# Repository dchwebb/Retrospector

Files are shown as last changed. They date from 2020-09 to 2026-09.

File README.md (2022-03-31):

# Retrospector
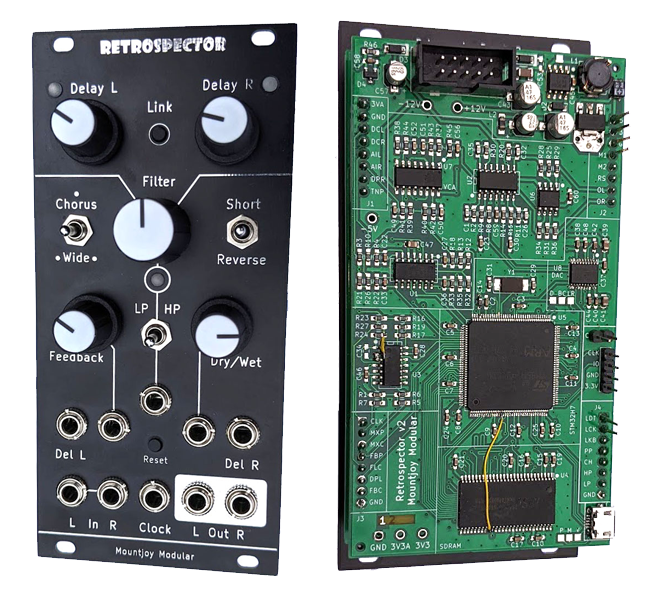
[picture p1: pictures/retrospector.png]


Retrospector is a Eurorack format stereo digital delay. 

Delay times can be set clocked or free-running and left and right channels can be independent or the right channel set as a multiple of the left channel. The delay times are switchable between short, long and reversed with maximum delay times over 5 minutes.

The feedback path can be filtered with settings allowing a sweep from low pass to high pass, or either separately. The delayed signal can be modulated for subtle chorussing effects or left and right channels fed back into each other to widen dual mono sources.

The feedback control allows greater than 100% regeneration allowing the delay to increase the volume of the delayed signal.

Three RGB LEDs display the delay times (using different colours to indicate clocking and channel linking) and the filter status (white to red with increasing low pass filtering and white to blue for high pass).

A USB port is available on the rear of the module providing configuration, debug and upgrade options via a serial interface.

# Technical
The module is constructed from a sandwich of three PCBs. The front panel is held to the control PCB using the potentiometers and jack sockets with light guides directing the RGB LEDs from the control PCB. The control PCB also houses the LED driver. All other components are on the component PCB and this is attached to the control PCB with standard 2.54mm headers. The component board is a 4 layer PCB; the others have 2 layers.

Retrospector is built around an STM32H743 microcontroller clocked at 400MHz. The MCU uses a pair of multi-channel 16-bit ADCs to digitise the stereo audio input signal and the various potentiometer and control voltage inputs.

The MCU controls the external DAC with I2S at 16 bits. The MCU's internal 12-bit DACs are used to control the linear VCA that carries out stereo mixing of the digital wet signal and analog dry signal.

Delay samples are held in external 32MB SDRAM controlled by the MCU's FMC peripheral. The MCU's internal memory is mainly used for DMA buffers and FIR filter buffers (better performance than the slower external RAM). The MCU also has both data and instruction caches which are used to greatly improve performance.

The three RGB LEDs are controlled by a Toshiba 9 channel LED driver (TB62781FNG) with the MCU setting colour and brightness over SPI and DMA.

The MCU also supports a USB micro-B port to allow upgrades, configuration and debugging via a serial console:

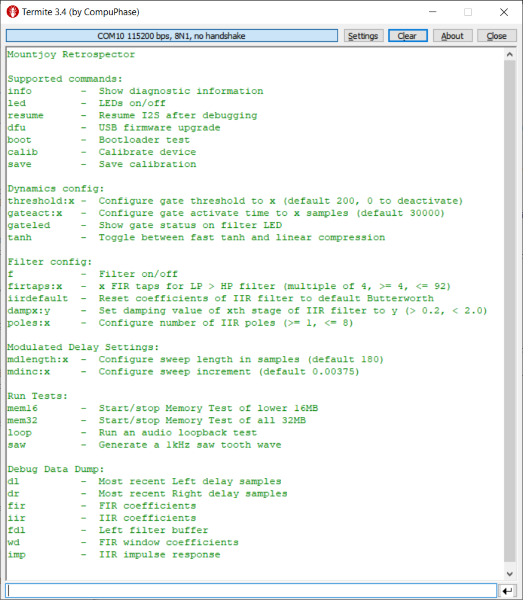
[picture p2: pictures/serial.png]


Annotated component PCB
-----------------------
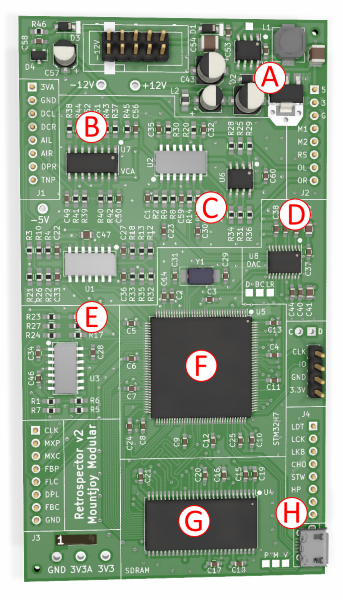
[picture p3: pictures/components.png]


A) A switched-mode power supply (Texas Instruments LM2675) converts the 12V rail to 5V which is then converted to 3.3V using an LDO. THe 5V rail also powers the RGB LEDs.

B) The mix control uses a 4 channel linear VCA (Alfa AS3364D) to control the Wet/Dry mix. This keeps the dry signal analog throughout.

C) The Output signals are mixed and inverted (to preserve signal polarity) with a TL074 and a TL072 op-amp.

D) The digital Wet signal is converted to analog using a Texas Instruments PCM5100 DAC.

E) The analog input signals (audio and control voltage) are scaled and mixed using a pair of MCP6004 op-amps.

F) The microcontroller is an STM32H743 running at 400MHz.

G) The delay beffers are stored in an external 32MB RAM module (ISSI IS42S16160J) allowing for over 5 minutes of stereo delay.

Errata
------
There were two errors on v2 hardware:

1. OpAmp U3 pin 2 and 3 incorrectly swapped. Bodge is to ground pin 3 of U3, remove capacitor C34, lift U3 pin 2 and connect it with a bodge wire to pad 2 of R24.
2. DRAM address line 12 was not connected. Bodge is to connect DRAM Pin 36 to MCU Pin 87.
3. Swapped C54 (tantalum 22uF) for ceramic 47uF (1206 25V X5R).

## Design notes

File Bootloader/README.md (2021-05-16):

# Boottest_H743
Test running bootloader from different Flash address. Project tests basic blinky functionality in a loop and from a timer interrupt to establish that running from different flash region works.

Flash start location is set in linker script to Bank 2 sector 1:

```
FLASH (rx)     : ORIGIN = 0x08100000, LENGTH = 1024K
```

assembly startup script then takes origin of vector table and updates SCB->VTOR register:

```
  ldr r3, =0xe000ed00    // SCB location
  ldr r2, =g_pfnVectors  // Location of vector table in Flash (set by linker)
  str r2, [r3, #8]       // store vector table location to offset 8 of SCB which is VTOR
```

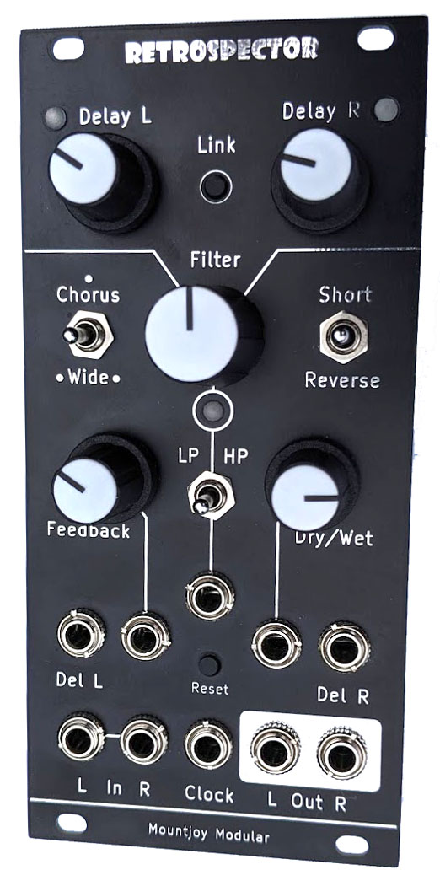
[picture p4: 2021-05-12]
pictures/front.jpg

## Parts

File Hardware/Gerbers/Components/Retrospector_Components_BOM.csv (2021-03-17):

Comment | Designator | Footprint | LCSC Part #
100pF | C1, C26, C32, C35, | C_0603_HandSoldering | C14858
100nF | C2, C3, C4, C5, C6, C7, C8, C9, C10, C11, C12, C13, C14, C15, C16, C17, C18, C19, C20, C21, C37, C38, C40, C44, C53, C58, | C_0603_HandSoldering | C14663
1.5nF | C22, C27, C28, C33, C34, C36, | C_0603_HandSoldering | C1595
1nF | C23, C30, | C_0603_HandSoldering | C1588
2.2uF | C24, C25, C42, C46, C48, C59, C60, | C_0603_HandSoldering | C23630
30pF | C29, C31, | C_0603_HandSoldering | C22397
10uF | C39, C41, C47, | C_0805 | C15850
47uF | C43, C61, | CP_Elec_5x5.8 | C134798
10nF | C45, C56, | C_0603_HandSoldering | C57112
560pF | C49, C50, C51, C52, | C_0603_HandSoldering | C84721
22uF | C57, C62, | CP_Elec_4x5.8 | C134793
1N5819 | D1, D2, D3, | D_SOD-123 | C8598
LM4040DBZ-5 | D4, | SOT-23 | C156291
L | L2, | L_0805_HandSoldering | C1046
75k | R1, | R_0603_HandSoldering | C23242
47k | R2, R6, R7, R10, R11, R18, R22, R24, R33, | R_0603_HandSoldering | C25819
20k | R3, R12, | R_0603_HandSoldering | C4184
6k8 | R4, R13, | R_0603_HandSoldering | C23212
91k | R5, R16, | R_0603_HandSoldering | C23265
2k2 | R8, R14, R46, | R_0603_HandSoldering | C4190
10k | R9, R15, R25, R28, R31, R34, | R_0603_HandSoldering | C25804
56k | R17, | R_0603_HandSoldering | C23206
100k | R19, R26, R27, R35, | R_0603_HandSoldering | C25803
30k | R20, R30, R37, R38, R39, R40, | R_0603_HandSoldering | C22984
68k | R21, R23, R32, | R_0603_HandSoldering | C23231
1k | R29, R36, | R_0603_HandSoldering | C21190
510R | R41, R42, R43, R44, | R_0603_HandSoldering | C23193
100R | R45, | R_0603_HandSoldering | C22775
MCP6004 | U1, U3, | SOIC-14_N | C116668
TL074 | U2, | SOIC-14_N | C6964
IS42S16800F-7TLI | U4, | TSOP-II-54_22.2x10.16mm_P0.8mm | C91278
STM32H743ZITx | U5, | LQFP-144_20x20mm_P0.5mm | C114408
TL072 | U6, | SOIC-8_3.9x4.9mm_Pitch1.27mm | C6961
PCM5100APW | U8, | SSOP-20_4.4x6.5mm_Pitch0.65mm_Round_Pads | C131154
LM2675M-5 | U9, | SOIC-8_3.9x4.9mm_Pitch1.27mm | C180371
8MHz 20pF | Y1, | Crystal_SMD_5032-2pin_5.0x3.2mm_HandSoldering | C115962

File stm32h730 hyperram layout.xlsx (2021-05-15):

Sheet: ProductsList
Part Number | General Description | Marketing Status | Core | Operating Frequency (MHz) | Co-Processor type | Co-Processor frequency (MHz) max | Flash Size (kB) (Prog) | Dual-bank Flash | RAM Size (kB) | ITCM/DTCM RAM (kB) | Timers (16-bit) typ | Timers (32-bit) typ | Other timer functions | A/D Converters 12-bit |  | A/D Converters 16-bit |  | D/A Converters (12-bit) typ | Comparator | I/Os (High Current) | Display controller | CAN FD typ | I2C typ | SPI typ | I2S typ | USART typ | UART typ | External Memory Interfaces | USB Type | Crypto-HASH | TRNG typ | SMPS | Supply Voltage (V) min | Supply Voltage (V) max | Supply Current (µA) (@ Lowest Power) typ | Supply Current (µA) (Run Mode (per MHz)) typ | Operating Temperature (°C) min | Operating Temperature (°C) max | Buy On Line
 |  |  |  |  |  |  |  |  |  |  |  |  |  | Number of A/D Converters typ | Number of Channels typ | Number of A/D Converters typ | Number of Channels typ
STM32H735IG (https://www.st.com/en/product/stm32h735ig.html) | High-performance and DSP with DP-FPU, Arm Cortex-M7 MCU with 1 MByte Flash, 564 KBytes RAM, 550 MHz CPU, L1 cache, external memory interface, SMPS, subset of peripherals including a Crypto accelerator | Active | Arm Cortex-M7 | 550 | Cordic,FMAC | 275 | 1024 | false | 564 | 64/128 | 17 | 4 | Dual Watchdog,LP timer,RTC,SysTick | 1 | 12,17 | 2 | 18,22 | 2 | 2 | 119,128 | Segment LCD | 3 | 5 | 6 | 4 | 5 | 6 | Dual Quad SPI,FMC | USB OTG HS | AES,DES/TDES,HMAC,MD5,SHA | true | Internal | 1.62 | 3.6 | 4 | 150 | -40 | 125,85 | true
STM32H723VE (https://www.st.com/en/product/stm32h723ve.html) | High-performance and DSP with DP-FPU, Arm Cortex-M7 MCU with 512 Kbytes Flash, 564 Kbytes RAM, 550 MHz CPU, L1 cache, external memory interface, subset of peripherals | Active | Arm Cortex-M7 | 550 | Cordic,FMAC | 275 | 512 | false | 564 | 64/128 | 17 | 4 | Dual Watchdog,HR timer,LP timer,RTC,SysTick | 1 | 17,4 | 2 | 14 | - | 2 | 80 | Segment LCD | 3 | 5 | 5 | 4 | 5 | 6 | Dual Quad SPI,FMC | USB OTG HS | - | true | - | 1.62,1.71 | 3.6 | 4 | 270 | -40 | 85 | false
STM32H723VG (https://www.st.com/en/product/stm32h723vg.html) | High-performance and DSP with DP-FPU, Arm Cortex-M7 MCU with 1 MByte Flash, 564 Kbytes RAM, 550 MHz CPU, L1 cache, external memory interface, subset of peripherals | Active | Arm Cortex-M7 | 550 | Cordic,FMAC | 275 | 1024 | false | 564 | 64/128 | 17 | 4 | Dual Watchdog,HR timer,LP timer,RTC,SysTick | 1 | 17,4 | 2 | 14 | - | 2 | 80 | Segment LCD | 3 | 5 | 5 | 4 | 5 | 6 | Dual Quad SPI,FMC | USB OTG HS | - | true | - | 1.62,1.71 | 3.6 | 4 | 270 | -40 | 85 | false,true
STM32H723ZE (https://www.st.com/en/product/stm32h723ze.html) | High-performance and DSP with DP-FPU, Arm Cortex-M7 MCU with 512 Kbytes Flash, 564 Kbytes RAM, 550 MHz CPU, L1 cache, external memory interface, subset of peripherals | Active | Arm Cortex-M7 | 550 | Cordic,FMAC | 275 | 512 | false | 564 | 64/128 | 17 | 4 | Dual Watchdog,HR timer,LP timer,RTC,SysTick | 1 | 12,17 | 2 | 16,18 | - | 2 | 112,114 | Segment LCD | 3 | 5 | 6 | 4 | 5 | 6 | Dual Quad SPI,FMC | USB OTG HS | - | true | - | 1.62 | 3.6 | 4 | 270 | -40 | 85 | false
STM32H723ZG (https://www.st.com/en/product/stm32h723zg.html) | High-performance and DSP with DP-FPU, Arm Cortex-M7 MCU with 1 MByte Flash, 564 KB RAM, 550 MHz CPU, L1 cache, external memory interface, subset of peripherals | Active | Arm Cortex-M7 | 550 | Cordic,FMAC | 275 | 1024 | false | 564 | 64/128 | 17 | 4 | Dual Watchdog,HR timer,LP timer,RTC,SysTick | 1 | 12,17 | 2 | 16,18 | - | 2 | 112,114 | Segment LCD | 3 | 5 | 6 | 4 | 5 | 6 | Dual Quad SPI,FMC | USB OTG HS | - | true | - | 1.62 | 3.6 | 4 | 270 | -40 | 85 | false,true
STM32H725AE (https://www.st.com/en/product/stm32h725ae.html) | High-performance and DSP with DP-FPU, Arm Cortex-M7 MCU with 512 KBytes Flash, 564 KBytes RAM, 550 MHz CPU, L1 cache, external memory interface, SMPS, subset of peripherals | Active | Arm Cortex-M7 | 550 | Cordic,FMAC | 275 | 512 | - | 564 | 64/128 | 17 | 4 | Dual Watchdog,HR timer,LP timer,RTC,SysTick | 1 | 15 | 2 | 22 | 2 | 2 | 121 | Segment LCD | 3 | 5 | 4 | 4 | 5 | 6 | Dual Quad SPI,FMC | USB OTG HS | - | true | Internal | 1.62 | 3.6 | 4 | 150 | -40 | 85 | true
STM32H725AG (https://www.st.com/en/product/stm32h725ag.html) | High-performance and DSP with DP-FPU, Arm Cortex-M7 MCU with 1 MByte Flash, 564 KBytes RAM, 550 MHz CPU, L1 cache, external memory interface, SMPS, subset of peripherals | Active | Arm Cortex-M7 | 550 | Cordic,FMAC | 275 | 1024 | - | 564 | 64/128 | 17 | 4 | Dual Watchdog,HR timer,LP timer,RTC,SysTick | 1 | 15 | 2 | 22 | 2 | 2 | 121 | Segment LCD | 3 | 5 | 4 | 4 | 5 | 6 | Dual Quad SPI,FMC | USB OTG HS | - | true | Internal | 1.62 | 3.6 | 4 | 150 | -40 | 125,85 | true
STM32H725IE (https://www.st.com/en/product/stm32h725ie.html) | High-performance and DSP with DP-FPU, Arm Cortex-M7 MCU with 512 KBytes Flash, 564 KBytes RAM, 550 MHz CPU, L1 cache, external memory interface, SMPS, subset of peripherals | Active | Arm Cortex-M7 | 550 | FMAC, Cordic | 275 | 512 | - | 564 | 64/128 | 17 | 4 | Dual Watchdog,HR timer,LP timer,RTC,SysTick | 1 | 12,17 | 2 | 18,22 | 2 | 2 | 119,128 | Segment LCD | 3 | 5 | 6 | 4 | 5 | 6 | Dual Quad SPI,FMC | USB OTG HS | - | true | Internal | 1.62 | 3.6 | 4 | 150 | -40 | 85 | -
STM32H725IG (https://www.st.com/en/product/stm32h725ig.html) | High-performance and DSP with DP-FPU, Arm Cortex-M7 MCU with 1 MByte Flash, 564 KBytes RAM, 550 MHz CPU, L1 cache, external memory interface, SMPS, subset of peripherals | Active | Arm Cortex-M7 | 550 | Cordic,FMAC | 275 | 1024 | - | 564 | 64/128 | 17 | 4 | Dual Watchdog,HR timer,LP timer,RTC,SysTick | 1 | 17,18 | 2 | 18,22 | 2 | 2 | 119,128 | Segment LCD | 3 | 5 | 6 | 4 | 5 | 6 | Dual Quad SPI,FMC | USB OTG HS | - | true | Internal | 1.62 | 3.6 | 4 | 150 | -40 | 125,85 | false
STM32H725RE (https://www.st.com/en/product/stm32h725re.html) | High-performance and DSP with DP-FPU, Arm Cortex-M7 MCU with 512 KBytes Flash, 564 KBytes RAM, 550 MHz CPU, L1 cache, external memory interface, SMPS, subset of peripherals | Active | Arm Cortex-M7 | 550 | FMAC, Cordic | 275 | 512 | - | 564 | 64/128 | 17 | 4 | Dual Watchdog,HR timer,LP timer,RTC,SysTick | 1 | 2 | 2 | 14 | 2 | 2 | 46 | Segment LCD | 2 | 4 | 4 | 4 | 4 | 4 | Dual Quad SPI,FMC | USB OTG HS | - | true | Internal | 1.71 | 3.6 | 4 | 150 | -40 | 85 | false
STM32H725RG (https://www.st.com/en/product/stm32h725rg.html) | High-performance and DSP with DP-FPU, Arm Cortex-M7 MCU with 1 MByte Flash, 564 KBytes RAM, 550 MHz CPU, L1 cache, external memory interface, SMPS, subset of peripherals | Active | Arm Cortex-M7 | 550 | Cordic,FMAC | 275 | 1024 | - | 564 | 64/128 | 17 | 4 | Dual Watchdog,HR timer,LP timer,RTC,SysTick | 1 | 2 | 2 | 14 | 2 | 2 | 46 | Segment LCD | 2 | 4 | 4 | 4 | 4 | 4 | Dual Quad SPI,FMC | USB OTG HS | - | true | Internal | 1.71 | 3.6 | 4 | 150 | -40 | 125,85 | false
STM32H725VE (https://www.st.com/en/product/stm32h725ve.html) | High-performance and DSP with DP-FPU, Arm Cortex-M7 MCU with 512 KBytes Flash, 564 KBytes RAM, 550 MHz CPU, L1 cache, external memory interface, SMPS, subset of peripherals | Active | Arm Cortex-M7 | 550 | FMAC, Cordic | 275 | 512 | - | 564 | 64/128 | 17 | 4 | Dual Watchdog,HR timer,LP timer,RTC,SysTick | 1 | 4 | 2 | 14 | 2 | 2 | 67 | Segment LCD | 3 | 5 | 5 | 4 | 4 | 4,5 | Dual Quad SPI,FMC | USB OTG HS | - | true | Internal | 1.62,1.71 | 3.6 | 4 | 150 | -40 | 85 | false
STM32H725VG (https://www.st.com/en/product/stm32h725vg.html) | High-performance and DSP with DP-FPU, Arm Cortex-M7 MCU with 1 MByte Flash, 564 KBytes RAM, 550 MHz CPU, L1 cache, external memory interface, SMPS, subset of peripherals | Active | Arm Cortex-M7 | 550 | Cordic,FMAC | 275 | 1024 | - | 564 | 64/128 | 17 | 4 | Dual Watchdog,HR timer,LP timer,RTC,SysTick | 1 | 2,4 | 2 | 14 | 2 | 2 | 67 | Segment LCD | 3 | 5 | 5,6 | 4 | 4 | 5 | Dual Quad SPI,FMC | USB OTG HS | - | true | Internal | 1.62,1.71 | 3.6 | 4 | 150 | -40 | 125,85 | true
STM32H725ZE (https://www.st.com/en/product/stm32h725ze.html) | High-performance and DSP with DP-FPU, Arm Cortex-M7 MCU with 512 KBytes Flash, 564 KBytes RAM, 550 MHz CPU, L1 cache, external memory interface, SMPS, subset of peripherals | Active | Arm Cortex-M7 | 550 | FMAC, Cordic | 275 | 512 | - | 564 | 64/128 | 17 | 4 | Dual Watchdog,HR timer,LP timer,RTC,SysTick | 1 | 12 | 2 | 18 | 2 | 2 | 97 | Segment LCD | 3 | 5 | 6 | 4 | 5 | 6 | Dual Quad SPI,FMC | USB OTG HS | - | true | Internal | 1.62 | 3.6 | 4 | 150 | -40 | 85 | -
STM32H725ZG (https://www.st.com/en/product/stm32h725zg.html) | High-performance and DSP with DP-FPU, Arm Cortex-M7 MCU with 1 MByte Flash, 564 KBytes RAM, 550 MHz CPU, L1 cache, external memory interface, SMPS, subset of peripherals | Active | Arm Cortex-M7 | 550 | Cordic,FMAC | 275 | 1024 | - | 564 | 64/128 | 17 | 4 | Dual Watchdog,HR timer,LP timer,RTC,SysTick | 1 | 12 | 2 | 18 | 2 | 2 | 97 | LCD TFT Controller | 3 | 5 | 6 | 4 | 5 | 6 | Dual Quad SPI,FMC | USB OTG FS + USB OTG FS/HS | - | true | Internal | 1.62 | 3.6 | 4 | 150 | -40 | 125,85 | false,true
STM32H730AB (https://www.st.com/en/product/stm32h730ab.html) | High-performance and DSP with DP-FPU, Arm Cortex-M7 MCU with 128 Kbytes Flash, 564 Kbytes RAM, 550 MHz CPU, L1 cache, external memory interface, SMPS, subset of peripherals including a Crypto accelerator | Active | Arm Cortex-M7 | 550 | Cordic,FMAC | 275 | 128 | false | 564 | 64/128 | 17 | 4 | Dual Watchdog,LP timer,RTC,SysTick | 1 | 15 | 2 | 22 | 2 | 2 | - | Segment LCD | 3 | 5 | 6 | 4 | 5 | 6 | Dual Octo SPI,FMC | USB OTG HS | AES,DES/TDES,HMAC,MD5,SHA | true | Internal | 1.62 | 3.6 | 4 | 150 | -40 | 85 | true
STM32H730IB (https://www.st.com/en/product/stm32h730ib.html) | High-performance and DSP with DP-FPU, Arm Cortex-M7 MCU with 128 Kbytes Flash, 564 Kbytes RAM, 550 MHz CPU, L1 cache, external memory interface, SMPS, subset of peripherals including a Crypto accelerator | Active | Arm Cortex-M7 | 550 | Cordic,FMAC | 275 | 128 | false | 564 | 64/128 | 17 | 4 | Dual Watchdog,LP timer,RTC,SysTick | 1 | 12,17 | 2 | 18,22 | 2 | 2 | - | Segment LCD | 3 | 5 | 6 | 4 | 5 | 6 | Dual Octo SPI,FMC | USB OTG HS | AES,DES/TDES,HMAC,MD5,SHA | true | Internal | 1.62 | 3.6 | 4 | 150 | -40 | 85 | true
STM32H730VB (https://www.st.com/en/product/stm32h730vb.html) | High-performance and DSP with DP-FPU, Arm Cortex-M7 MCU with 128 Kbytes Flash, 564 Kbytes RAM, 550 MHz CPU, L1 cache, external memory interface, subset of peripherals including a Crypto accelerator | Active | Arm Cortex-M7 | 550 | Cordic,FMAC | 275 | 128 | false | 564 | 64/128 | 17 | 4 | Dual Watchdog,LP timer,RTC,SysTick | 1 | 17,4 | 2 | 14 | 2 | 2 | - | Segment LCD | 3 | 5 | 6 | 4 | 5 | 6 | Dual Octo SPI,FMC | USB OTG HS | AES,DES/TDES,HMAC,MD5,SHA | true | Internal | 1.62,1.71 | 3.6 | 4 | 270 | -40 | 85 | true
STM32H730ZB (https://www.st.com/en/product/stm32h730zb.html) | High-performance and DSP with DP-FPU, Arm Cortex-M7 MCU with 128 Kbytes Flash, 564 Kbytes RAM, 550 MHz CPU, L1 cache, external memory interface, subset of peripherals, including a Crypto accelerator | Active | Arm Cortex-M7 | 550 | Cordic,FMAC | 275 | 128 | false | 564 | 64/128 | 17 | 4 | Dual Watchdog,LP timer,RTC,SysTick | 1 | 12,17 | 2 | 16,18 | 2 | 2 | - | Segment LCD | 3 | 5 | 6 | 4 | 5 | 6 | Dual Octo SPI,FMC | USB OTG HS | AES,DES/TDES,HMAC,MD5,SHA | true | Internal | 1.62 | 3.6 | 4 | 270 | -40 | 85 | true
STM32H733VG (https://www.st.com/en/product/stm32h733vg.html) | High-performance and DSP with DP-FPU, Arm Cortex-M7 MCU with 1 MByte Flash, 564 Kbytes RAM, 550 MHz CPU, L1 cache, external memory interface, subset of peripherals including a Crypto accelerator | Active | Arm Cortex-M7 | 550 | Cordic,FMAC | 275 | 1024 | false | 564 | 64/128 | 17 | 4 | Dual Watchdog,LP timer,RTC,SysTick | 1 | 4 | 2 | 14 | 2 | 2 | 80 | Segment LCD | 3 | 5 | 5 | 4 | 5 | 6 | Dual Quad SPI,FMC | USB OTG HS | - | true | - | 1.62,1.71 | 3.6 | 4 | 270 | -40 | 85 | true
STM32H733ZG (https://www.st.com/en/product/stm32h733zg.html) | High-performance and DSP with DP-FPU, Arm Cortex-M7 MCU with 1 MByte Flash, 564 Kbytes RAM, 550 MHz CPU, L1 cache, external memory interface, subset of peripherals, including a Crypto accelerator | Active | Arm Cortex-M7 | 550 | Cordic,FMAC | 275 | 1024 | false | 564 | 64/128 | 17 | 4 | Dual Watchdog,LP timer,RTC,SysTick | 1 | 11,12 | 2 | 18,20 | 2 | 2 | 112,114 | Segment LCD | 3 | 5 | 6 | 4 | 5 | 6 | Dual Quad SPI,FMC | USB OTG FS | - | true | - | 1.62 | 3.6 | 4 | 270 | -40 | 85 | true
STM32H735AG (https://www.st.com/en/product/stm32h735ag.html) | High-performance and DSP with DP-FPU, Arm Cortex-M7 MCU with 1 MByte Flash, 564 KBytes RAM, 550 MHz CPU, L1 cache, external memory interface, SMPS, subset of peripherals including a Crypto accelerator | Active | Arm Cortex-M7 | 550 | Cordic,FMAC | 275 | 1024 | false | 564 | 64/128 | 17 | 4 | Dual Watchdog,LP timer,RTC,SysTick | 1 | 15 | 2 | 22 | 2 | 2 | 121 | Segment LCD | 3 | 5 | 4 | 4 | 5 | 6 | Dual Quad SPI,FMC | USB OTG HS | AES,DES/TDES,HMAC,MD5,SHA | true | Internal | 1.62 | 3.6 | 4 | 150 | -40 | 85 | true
STM32H735RG (https://www.st.com/en/product/stm32h735rg.html) | High-performance and DSP with DP-FPU, Arm Cortex-M7 MCU with 1 MByte Flash, 564 KBytes RAM, 550 MHz CPU, L1 cache, external memory interface, SMPS, subset of peripherals including a Crypto accelerator | Active | Arm Cortex-M7 | 550 | Cordic,FMAC | 275 | 1024 | false | 564 | 64/128 | 17 | 4 | Dual Watchdog,LP timer,RTC,SysTick | 1 | 2 | 2 | 14 | 2 | 2 | 46 | Segment LCD | 2 | 4 | 4 | 4 | 4 | 4 | Dual Quad SPI,FMC | USB OTG HS | AES,DES/TDES,HMAC,MD5,SHA | true | Internal | 1.71 | 3.6 | 4 | 150 | -40 | 85 | false
STM32H735VG (https://www.st.com/en/product/stm32h735vg.html) | High-performance and DSP with DP-FPU, Arm Cortex-M7 MCU with 1 MByte Flash, 564 KBytes RAM, 550 MHz CPU, L1 cache, external memory interface, SMPS, subset of peripherals including a Crypto accelerator | Active | Arm Cortex-M7 | 550 | Cordic,FMAC | 275 | 1024 | false | 564 | 64/128 | 17 | 4 | Dual Watchdog,LP timer,RTC,SysTick | 1 | 2,4 | 2 | 14 | 2 | 2 | 67 | Segment LCD | 3 | 5 | 5,6 | 4 | 4 | 5 | Dual Quad SPI,FMC | USB OTG HS | AES,DES/TDES,HMAC,MD5,SHA | true | Internal | 1.62,1.71 | 3.6 | 4 | 150 | -40 | 85 | true
STM32H735ZG (https://www.st.com/en/product/stm32h735zg.html) | High-performance and DSP with DP-FPU, Arm Cortex-M7 MCU with 1 MByte Flash, 564 KBytes RAM, 550 MHz CPU, L1 cache, external memory interface, SMPS, subset of peripherals including a Crypto accelerator | Active | Arm Cortex-M7 | 550 | Cordic,FMAC | 275 | 1024 | - | 564 | 64/128 | 17 | 4 | Dual Watchdog,LP timer,RTC,SysTick | 1 | 12 | 2 | 18 | 2 | 2 | 97 | Segment LCD | 3 | 5 | 6 | 4 | 5 | 6 | Dual Quad SPI,FMC | USB OTG HS | AES,DES/TDES,HMAC,MD5,SHA | true | Internal | 1.62 | 3.6 | 4 | 150 | -40 | 85 | true
STM32H742AG (https://www.st.com/en/product/stm32h742ag.html) | High-performance and DSP with DP-FPU, Arm Cortex-M7 MCU with 1MByte of Flash memory, 692KB RAM, 480 MHz CPU, L1 cache, external memory interface, subset of peripherals | Active | Arm Cortex-M7 | 480 | - | - | 1024 | true | 692 | - | 12 | 2 | Dual Watchdog,HR timer,LP timer,RTC,SysTick | 1 | - | - | 32 | 2 | 2 | 132 | - | 2 | 4 | 6 | 3 | 4 | 4 | Dual Quad SPI,FMC | USB OTG FS,USB OTG FS + USB OTG FS/HS | - | true | - | 1.62 | 3.6 | 4 | 270 | -40 | 85 | -
STM32H742AI (https://www.st.com/en/product/stm32h742ai.html) | High-performance and DSP with DP-FPU, Arm Cortex-M7 MCU with 2MBytes of Flash memory, 692KB RAM, 480 MHz CPU, L1 cache, external memory interface, subset of peripherals | Active | Arm Cortex-M7 | 480 | - | - | 2048 | true | 692 | - | 12 | 2 | Dual Watchdog,HR timer,LP timer,RTC,SysTick | - | - | - | 32 | 2 | 2 | 132 | - | 2 | 4 | 6 | 3 | 4 | 4 | Dual Quad SPI,FMC | USB OTG FS,USB OTG FS + USB OTG FS/HS | - | true | - | 1.62 | 3.6 | 4 | 270 | -40 | 85 | -
STM32H742BG (https://www.st.com/en/product/stm32h742bg.html) | High-performance and DSP with DP-FPU, Arm Cortex-M7 MCU with 1MBytes of Flash memory, 692KBytes RAM, 480 MHz CPU, L1 cache, external memory interface, subset of peripherals | Active | Arm Cortex-M7 | 480 | - | - | 1024 | true | 692 | - | 12 | 2 | Dual Watchdog,HR timer,LP timer,RTC,SysTick | - | - | - | 32 | 2 | 2 | 168 | - | 2 | 4 | 6 | 3 | 4 | 4 | Dual Quad SPI,FMC | USB OTG FS,USB OTG FS + USB OTG FS/HS | - | true | - | 1.62 | 3.6 | 4 | 270 | -40 | 85 | -
STM32H742BI (https://www.st.com/en/product/stm32h742bi.html) | High-performance and DSP with DP-FPU, Arm Cortex-M7 MCU with 2MBytes of Flash memory, 692KBytes RAM, 480 MHz CPU, L1 cache, external memory interface, subset of peripherals | Active | Arm Cortex-M7 | 480 | - | - | 2048 | true | 692 | - | 12 | 2 | LP timer,RTC | - | - | - | 32 | 2 | 2 | 168 | - | 2 | 4 | 6 | 3 | 4 | 4 | Dual Quad SPI,FMC | USB OTG FS,USB OTG FS + USB OTG FS/HS | - | true | - | 1.62 | 3.6 | 4 | 270 | -40 | 85 | -
STM32H742IG (https://www.st.com/en/product/stm32h742ig.html) | High-performance and DSP with DP-FPU, Arm Cortex-M7 MCU with 1MBytes of Flash memory, 692KBytes RAM, 480 MHz CPU, L1 cache, external memory interface, subset of peripherals | Active | Arm Cortex-M7 | 480 | - | - | 1024 | true | 692 | - | 12 | 2 | Dual Watchdog,HR timer,LP timer,RTC,SysTick | - | - | - | 32 | 2 | 2 | 138 | - | 2 | 4 | 6 | 3 | 4 | 4 | Dual Quad SPI,FMC | USB OTG FS,USB OTG FS + USB OTG FS/HS | - | true | - | 1.62 | 3.6 | 4 | 270 | -40 | 85 | false
STM32H742II (https://www.st.com/en/product/stm32h742ii.html) | High-performance and DSP with DP-FPU, Arm Cortex-M7 MCU with 2MBytes of Flash memory, 692KBytes RAM, 480 MHz CPU, L1 cache, external memory interface, subset of peripherals | Active | Arm Cortex-M7 | 480 | - | - | 2048 | true | 692 | - | 12 | 2 | Dual Watchdog,HR timer,LP timer,RTC,SysTick | - | - | - | 32 | 2 | 2 | 138 | - | 2 | 4 | 6 | 3 | 4 | 4 | Dual Quad SPI,FMC | USB OTG FS,USB OTG FS + USB OTG FS/HS | - | true | - | 1.62 | 3.6 | 4 | 270 | -40 | 85 | false
STM32H742VG (https://www.st.com/en/product/stm32h742vg.html) | High-performance and DSP with DP-FPU, Arm Cortex-M7 MCU with 1MBytes of Flash memory, 692KB RAM, 480 MHz CPU, L1 cache, external memory interface, subset of peripherals | Active | Arm Cortex-M7 | 480 | - | - | 1024 | true | 692 | - | 12 | 2 | Dual Watchdog,HR timer,LP timer,RTC,SysTick | - | - | - | 16 | 2 | 2 | 82 | - | 2 | 4 | 5 | 3 | 4 | 4 | Dual Quad SPI,FMC | USB OTG FS,USB OTG FS + USB OTG FS/HS | - | true | - | 1.71 | 3.6 | 4 | 270 | -40 | 85 | true
STM32H742VI (https://www.st.com/en/product/stm32h742vi.html) | High-performance and DSP with DP-FPU, Arm Cortex-M7 MCU with 2MBytes of Flash memory, 692KB RAM, 480 MHz CPU, L1 cache, external memory interface, subset of peripherals | Active | Arm Cortex-M7 | 480 | - | - | 2048 | true | 692 | - | 12 | 2 | Dual Watchdog,HR timer,LP timer,RTC,SysTick | - | - | - | 16 | 2 | 2 | 82 | - | 2 | 4 | 5 | 3 | 4 | 4 | Dual Quad SPI,FMC | USB OTG FS,USB OTG FS + USB OTG FS/HS | - | true | - | 1.71 | 3.6 | 4 | 270 | -40 | 85 | true
STM32H742XG (https://www.st.com/en/product/stm32h742xg.html) | High-performance and DSP with DP-FPU, Arm Cortex-M7 MCU with 1MByte of Flash memory, 692KB RAM, 480 MHz CPU, L1 cache, external memory interface, subset of peripherals | Active | Arm Cortex-M7 | 480 | - | - | 1024 | true | 692 | - | 12 | 2 | Dual Watchdog,HR timer,LP timer,RTC,SysTick | - | - | - | 36 | 2 | 2 | 168 | - | 2 | 4 | 6 | 3 | 4 | 4 | Dual Quad SPI,FMC | USB OTG FS,USB OTG FS + USB OTG FS/HS | - | true | - | 1.62 | 3.6 | 4 | 270 | -40 | 85 | -
STM32H742XI (https://www.st.com/en/product/stm32h742xi.html) | High-performance and DSP with DP-FPU, Arm Cortex-M7 MCU with 2MBytes of Flash memory, 692KB RAM, 480 MHz CPU, L1 cache, external memory interface, subset of peripherals | Active | Arm Cortex-M7 | 480 | - | - | 2048 | true | 692 | - | 12 | 2 | Dual Watchdog,HR timer,LP timer,RTC,SysTick | - | - | - | 36 | 2 | 2 | 168 | - | 2 | 4 | 6 | 3 | 4 | 4 | Dual Quad SPI,FMC | USB OTG FS,USB OTG FS + USB OTG FS/HS | - | true | - | 1.62 | 3.6 | 4 | 270 | -40 | 85 | false
STM32H742ZG (https://www.st.com/en/product/stm32h742zg.html) | High-performance and DSP with DP-FPU, Arm Cortex-M7 MCU with 1MByte of Flash memory, 692KB RAM, 480 MHz CPU, L1 cache, external memory interface, subset of peripherals | Active | Arm Cortex-M7 | 480 | - | - | 1024 | true | 692 | - | 12 | 2 | Dual Watchdog,HR timer,LP timer,RTC,SysTick | - | - | - | 28 | 2 | 2 | 114 | - | 2 | 4 | 6 | 3 | 4 | 4 | Dual Quad SPI,FMC | USB OTG FS,USB OTG FS + USB OTG FS/HS | - | true | - | 1.62 | 3.6 | 4 | 270 | -40 | 85 | -
STM32H742ZI (https://www.st.com/en/product/stm32h742zi.html) | High-performance and DSP with DP-FPU, Arm Cortex-M7 MCU with 2MBytes of Flash memory, 692KB RAM, 480 MHz CPU, L1 cache, external memory interface, subset of peripherals | Active | Arm Cortex-M7 | 480 | - | - | 2048 | true | 692 | - | 12 | 2 | Dual Watchdog,HR timer,LP timer,RTC,SysTick | - | - | - | 28 | 2 | 2 | 114 | - | 2 | 4 | 6 | 3 | 4 | 4 | Dual Quad SPI,FMC | USB OTG FS,USB OTG FS + USB OTG FS/HS | - | true | - | 1.62 | 3.6 | 4 | 270 | -40 | 85 | -
STM32H743AG (https://www.st.com/en/product/stm32h743ag.html) | High-performance and DSP with DP-FPU, Arm Cortex-M7 MCU with 1 MByte of Flash memory, 1MB RAM, 480 MHz CPU, L1 cache, external memory interface, JPEG codec, large set of peripherals | Active | Arm Cortex-M7 | 480 | - | - | 1024 | true | 1024 | - | 12 | 2 | Dual Watchdog,HR timer,LP timer,RTC,SysTick | - | - | - | 32 | 2 | 2 | 132 | LCD TFT Controller | 2 | 4 | 6 | 3 | 4 | 4 | Dual Quad SPI,FMC | USB OTG FS + USB OTG FS/HS | - | true | - | 1.62 | 3.6 | 4 | 270 | -40 | 85 | -
STM32H743AI (https://www.st.com/en/product/stm32h743ai.html) | High-performance and DSP with DP-FPU, Arm Cortex-M7 MCU with 2MBytes of Flash memory, 1MB RAM, 480 MHz CPU, L1 cache, external memory interface, JPEG codec, large set of peripherals | Active | Arm Cortex-M7 | 480 | - | - | 2048 | true | 1024 | - | 12 | 2 | Dual Watchdog,HR timer,LP timer,RTC,SysTick | - | - | - | 32 | 2 | 2 | 132 | LCD TFT Controller | 2 | 4 | 6 | 3 | 4 | 4 | Dual Quad SPI,FMC | USB OTG FS + USB OTG FS/HS | - | true | - | 1.62 | 3.6 | 4 | 270 | -40 | 85 | true
STM32H743BG (https://www.st.com/en/product/stm32h743bg.html) | High-performance and DSP with DP-FPU, Arm Cortex-M7 MCU with 1MByte of Flash memory, 1MB RAM, 480 MHz CPU, L1 cache, external memory interface, JPEG codec, large set of peripherals | Active | Arm Cortex-M7 | 480 | - | - | 1024 | true | 1024 | - | 12 | 2 | Dual Watchdog,HR timer,LP timer,RTC,SysTick | - | - | - | 32 | 2 | 2 | 168 | - | 2 | 4 | 6 | 3 | 4 | 4 | Dual Quad SPI,FMC | USB OTG FS,USB OTG FS + USB OTG FS/HS | - | true | - | 1.62 | 3.6 | 4 | 270 | -40 | 85 | -
STM32H743BI (https://www.st.com/en/product/stm32h743bi.html) | High-performance and DSP with DP-FPU, Arm Cortex-M7 MCU with 2MBytes of Flash memory, 1MB RAM, 480 MHz CPU, L1 cache, external memory interface, JPEG codec, large set of peripherals | Active | Arm Cortex-M7 | 480 | - | - | 2048 | true | 1024 | - | 12 | 2 | Dual Watchdog,HR timer,LP timer,RTC,SysTick | - | - | - | 32 | 2 | 2 | 168 | LCD TFT Controller | 2 | 4 | 6 | 3 | 4 | 4 | Dual Quad SPI,FMC | USB OTG FS + USB OTG FS/HS | - | true | - | 1.62 | 3.6 | 4 | 270 | -40 | 85 | true
STM32H743IG (https://www.st.com/en/product/stm32h743ig.html) | High-performance and DSP with DP-FPU, Arm Cortex-M7 MCU with 1MByte of Flash memory, 1MB RAM, 480 MHz CPU, L1 cache, external memory interface, JPEG codec, large set of peripherals | Active | Arm Cortex-M7 | 480 | - | - | 1024 | true | 1024 | - | 12 | 2 | Dual Watchdog,HR timer,RTC,SysTick | - | - | 3 | 20,32 | 2 | 2 | 140 | Segment LCD | 2 | 4 | 6 | 3 | 4 | 4 | Dual Quad SPI,FMC | USB OTG FS + USB OTG FS/HS | - | true | - | 1.62 | 3.6 | 4 | 270 | -40 | 85 | false
STM32H743II (https://www.st.com/en/product/stm32h743ii.html) | High-performance and DSP with DP-FPU, Arm Cortex-M7 MCU with 2MBytes of Flash memory, 1MB RAM, 480 MHz CPU, Art Accelerator, L1 cache, external memory interface, large set of peripherals | Active | Arm Cortex-M7 | 480 | - | - | 2048 | true | 1024 | - | 12 | 2 | Dual Watchdog,HR timer,LP timer,RTC,SysTick | - | - | - | 32 | 2 | 2 | 140 | LCD TFT Controller | 2 | 4 | 6 | 3 | 4 | 4 | Dual Quad SPI,FMC | USB OTG FS + USB OTG FS/HS | - | true | - | 1.62 | 3.6 | 4 | 270 | -40 | 85 | false,true
STM32H743VG (https://www.st.com/en/product/stm32h743vg.html) | High-performance and DSP with DP-FPU, Arm Cortex-M7 MCU with 1MBytes of Flash memory, 1MB RAM, 480 MHz CPU, L1 cache, external memory interface, JPEG codec, large set of peripherals | Active | Arm Cortex-M7 | 480 | - | - | 1024 | true | 1024 | - | 12 | 2 | Dual Watchdog,HR timer,RTC,SysTick | - | - | - | 16 | 2 | 2 | 82 | - | 2 | 4 | 5 | 3 | 4 | 4 | Dual Quad SPI,FMC | USB OTG FS,USB OTG FS + USB OTG FS/HS | - | true | - | 1.71 | 3.6 | 4 | 270 | -40 | 85 | false
STM32H743VI (https://www.st.com/en/product/stm32h743vi.html) | High-performance and DSP with DP-FPU, Arm Cortex-M7 MCU with 2MBytes of Flash memory, 1MB RAM, 480 MHz CPU, Art Accelerator, L1 cache, external memory interface, large set of peripherals | Active | Arm Cortex-M7 | 480 | - | - | 2048 | true | 1024 | - | 12 | 2 | Dual Watchdog,HR timer,LP timer,RTC,SysTick | - | - | - | 16 | 2 | 2 | 82 | LCD TFT Controller | 2 | 4 | 5 | 3 | 4 | 4 | Dual Quad SPI,FMC | USB OTG FS + USB OTG FS/HS | - | true | - | 1.71 | 3.6 | 4 | 270 | -40 | 85 | false,true
STM32H743XG (https://www.st.com/en/product/stm32h743xg.html) | High-performance and DSP with DP-FPU, Arm Cortex-M7 MCU with 1MByte of Flash memory, 1MB RAM, 480 MHz CPU, L1 cache, external memory interface, JPEG codec, large set of peripherals | Active | Arm Cortex-M7 | 480 | - | - | 1024 | true | 1024 | - | 12 | 2 | Dual Watchdog,HR timer,LP timer,RTC,SysTick | - | - | - | 36 | 2 | 2 | 168 | - | 2 | 4 | 6 | 3 | 4 | 4 | Dual Quad SPI,FMC | USB OTG FS + USB OTG FS/HS | - | true | - | 1.62 | 3.6 | 4 | 270 | -40 | 85 | -
STM32H743XI (https://www.st.com/en/product/stm32h743xi.html) | High-performance and DSP with DP-FPU, Arm Cortex-M7 MCU with 2MBytes of Flash memory, 1MB RAM, 480 MHz CPU, Art Accelerator, L1 cache, external memory interface, large set of peripherals | Active | Arm Cortex-M7 | 480 | - | - | 2048 | true | 1024 | - | 12 | 2 | Dual Watchdog,HR timer,LP timer,RTC,SysTick | - | - | - | 36 | 2 | 2 | 168 | LCD TFT Controller | 2 | 4 | 6 | 3 | 4 | 4 | Dual Quad SPI,FMC | USB OTG FS + USB OTG FS/HS | - | true | - | 1.62 | 3.6 | 4 | 270 | -40 | 85 | false
STM32H743ZG (https://www.st.com/en/product/stm32h743zg.html) | High-performance and DSP with DP-FPU, Arm Cortex-M7 MCU with 1MByte of Flash memory, 1MB RAM, 480 MHz CPU, L1 cache, external memory interface, JPEG codec, large set of peripherals | Active | Arm Cortex-M7 | 480 | - | - | 1024 | true | 1024 | - | 12 | 2 | Dual Watchdog,HR timer,RTC,SysTick | - | - | - | 28 | 2 | 2 | 114 | - | 2 | 4 | 6 | 3 | 4 | 4 | Dual Quad SPI,FMC | USB OTG FS,USB OTG FS + USB OTG FS/HS | - | true | - | 1.62 | 3.6 | 4 | 270 | -40 | 85 | true
STM32H743ZI (https://www.st.com/en/product/stm32h743zi.html) | High-performance and DSP with DP-FPU, Arm Cortex-M7 MCU with 2MBytes of Flash memory, 1MB RAM, 480 MHz CPU, Art Accelerator, L1 cache, external memory interface, large set of peripherals | Active | Arm Cortex-M7 | 480 | - | - | 2048 | true | 1024 | - | 12 | 2 | LP timer | - | - | - | 28 | 2 | 2 | 114 | LCD TFT Controller | 2 | 4 | 6 | 3 | 4 | 4 | Dual Quad SPI,FMC | USB OTG FS + USB OTG FS/HS | - | true | - | 1.62 | 3.6 | 4 | 270 | -40 | 85 | true
STM32H745BG (https://www.st.com/en/product/stm32h745bg.html) | High-performance and DSP with DP-FPU, Arm Cortex-M7 + Cortex-M4 MCU with 1MBytes of Flash memory, 1MB RAM, 480 MHz CPU, Art Accelerator, L1 cache, external memory interface, large set of peripherals, SMPS | Active | Arm Cortex-M7+M4 Dual | 480 | - | 240 | 1024 | true | 1024 | - | 12 | 2 | Dual Watchdog,HR timer,LP timer,RTC,SysTick | - | - | - | 32 | 2 | 2 | 150 | LCD TFT Controller | 2 | 4 | 6 | 3 | 4 | 4 | Dual Quad SPI,FMC | USB OTG FS + USB OTG FS/HS | - | true | Internal | 1.62 | 3.6 | 4 | - | -40 | 85 | -
STM32H745BI (https://www.st.com/en/product/stm32h745bi.html) | High-performance and DSP with DP-FPU, Arm Cortex-M7 + Cortex-M4 MCU with 2MBytes of Flash memory, 1MB RAM, 480 MHz CPU, Art Accelerator, L1 cache, external memory interface, large set of peripherals, SMPS | Active | Arm Cortex-M7+M4 Dual | 480 | - | 240 | 2048 | true | 1024 | - | 12 | 2 | Dual Watchdog,HR timer,RTC,SysTick | - | - | - | 32 | 2 | 2 | 150 | - | 2 | 4 | 6 | 3 | 4 | 4 | Dual Quad SPI,FMC | USB OTG FS,USB OTG FS + USB OTG FS/HS | - | true | - | 1.62 | 3.6 | - | - | -40 | 125,85 | false
STM32H745IG (https://www.st.com/en/product/stm32h745ig.html) | High-performance and DSP with DP-FPU, Arm Cortex-M7 + Cortex-M4 MCU with 1MBytes of Flash memory, 1MB RAM, 480 MHz CPU, Art Accelerator, L1 cache, external memory interface, large set of peripherals, SMPS | Active | Arm Cortex-M7+M4 Dual | 480 | - | 240 | 1024 | true | 1024 | - | 12 | 2 | Dual Watchdog,HR timer,RTC,SysTick | - | - | - | 28,36 | 2 | 2 | 121,128 | - | 2 | 4 | 6 | 3 | 4 | 4 | Dual Quad SPI,FMC | USB OTG FS,USB OTG FS + USB OTG FS/HS | - | true | - | 1.62 | 3.6 | - | - | -40 | 85 | -
STM32H745II (https://www.st.com/en/product/stm32h745ii.html) | High-performance and DSP with DP-FPU, Arm Cortex-M7 + Cortex-M4 MCU with 2MBytes of Flash memory, 1MB RAM, 480 MHz CPU, Art Accelerator, L1 cache, external memory interface, large set of peripherals, SMPS | Active | Arm Cortex-M7+M4 Dual | 480 | - | 240 | 2048 | true | 1024 | - | 12 | 2 | Dual Watchdog,HR timer,RTC,SysTick | - | - | - | 28,36 | 2 | 2 | 121,128 | - | 2 | 4 | 6 | 3 | 4 | 4 | Dual Quad SPI,FMC | USB OTG FS,USB OTG FS + USB OTG FS/HS | - | true | - | 1.62 | 3.6 | - | - | -40 | 125,85 | false,true
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

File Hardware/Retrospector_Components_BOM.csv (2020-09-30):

Comment | Designator | Footprint | LCSC Part #
100nF | C1, C5, C7, C8, C9, C10, C11, C12, C13, C14, C15, C16, C17, C19, C20, C21, C24, C25, C26, C35, C37, C38, C42, C44, C46, | C_0603_HandSoldering | C14663
30pF | C2, C3, | C_0603_HandSoldering | C22397
2.2uF | C4, C6, C31, C33, | C_0805 | C49217
560pF | C18, C23, C27, C28, | C_0603_HandSoldering | C84721
10uF | C22, C43, | C_0805 | C15850
1.5nF | C29, C30, C32, C34, C45, | C_0603_HandSoldering | C1595
10uF | C36, | CP_Elec_3x5.3 | C249452
47uF | C41, | CP_Elec_5x5.3 | C134798
1nF | C47, C48, | C_0805 | C46653
100pF | C49, C50, C51, C52, | C_0805 | C1790
LM4040DBZ-5 | D2, | SOT-23 | C69316
1N5819 | D3, D4, | D_SOD-123 | C169540
L | L1, | L_0805_HandSoldering | C1046
30k | R1, R2, R10, R14, R18, R19, | R_0603_HandSoldering | C22984
510R | R3, R15, R16, R17, | R_0603_HandSoldering | C23193
91k | R4, R30, | R_0603_HandSoldering | C23265
100k | R5, R24, R26, | R_0603_HandSoldering | C25803
20k | R6, R8, | R_0603_HandSoldering | C4184
47k | R7, R9, R27, R28, R31, R34, | R_0603_HandSoldering | C25819
56k | R11, | R_0603_HandSoldering | C23206
6k8 | R12, R13, | R_0603_HandSoldering | C23212
1k | R20, R21, R42, R43, | R_0603_HandSoldering | C21190
2k2 | R22, R36, R37, | R_0603_HandSoldering | C4190
68k | R23, R25, | R_0603_HandSoldering | C23231
75k | R29, | R_0603_HandSoldering | C23242
330R | R32, R33, | R_0603_HandSoldering | C23138
10k | R38, R39, | R_0603_HandSoldering | C25804
33k | R40, R41, | R_0603_HandSoldering | C4216
STM32H743ZITx | U1, | LQFP-144_20x20mm_P0.5mm | C114408
IS42S16400J-xC | U2, | TSOP-II-54_22.2x10.16mm_P0.8mm | C69411
PCM5100APW | U3, | SSOP-20_4.4x6.5mm_Pitch0.65mm_Round_Pads | C131154
MCP6004 | U5, U6, | SOIC-14_N | C7378
TL074 | U7, | SOIC-14_N | C6964
LM1117-3.3 | U8, | SOT-223 | C6186

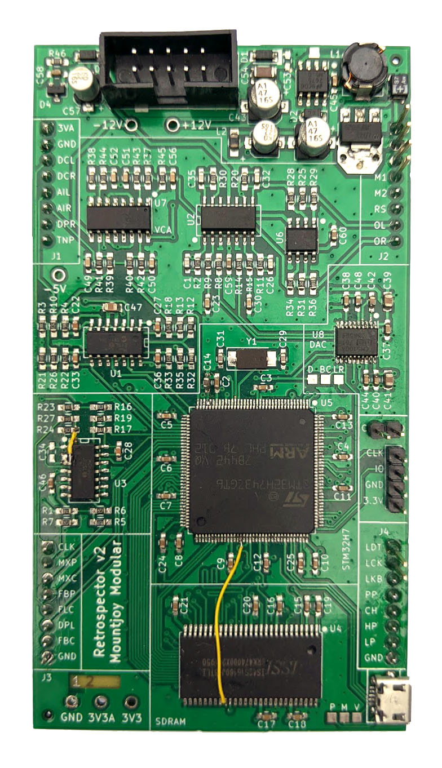
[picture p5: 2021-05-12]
pictures/components.jpg

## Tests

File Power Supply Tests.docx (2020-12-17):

TPS561201 5V

STM32F429:

3.312V 0.083A

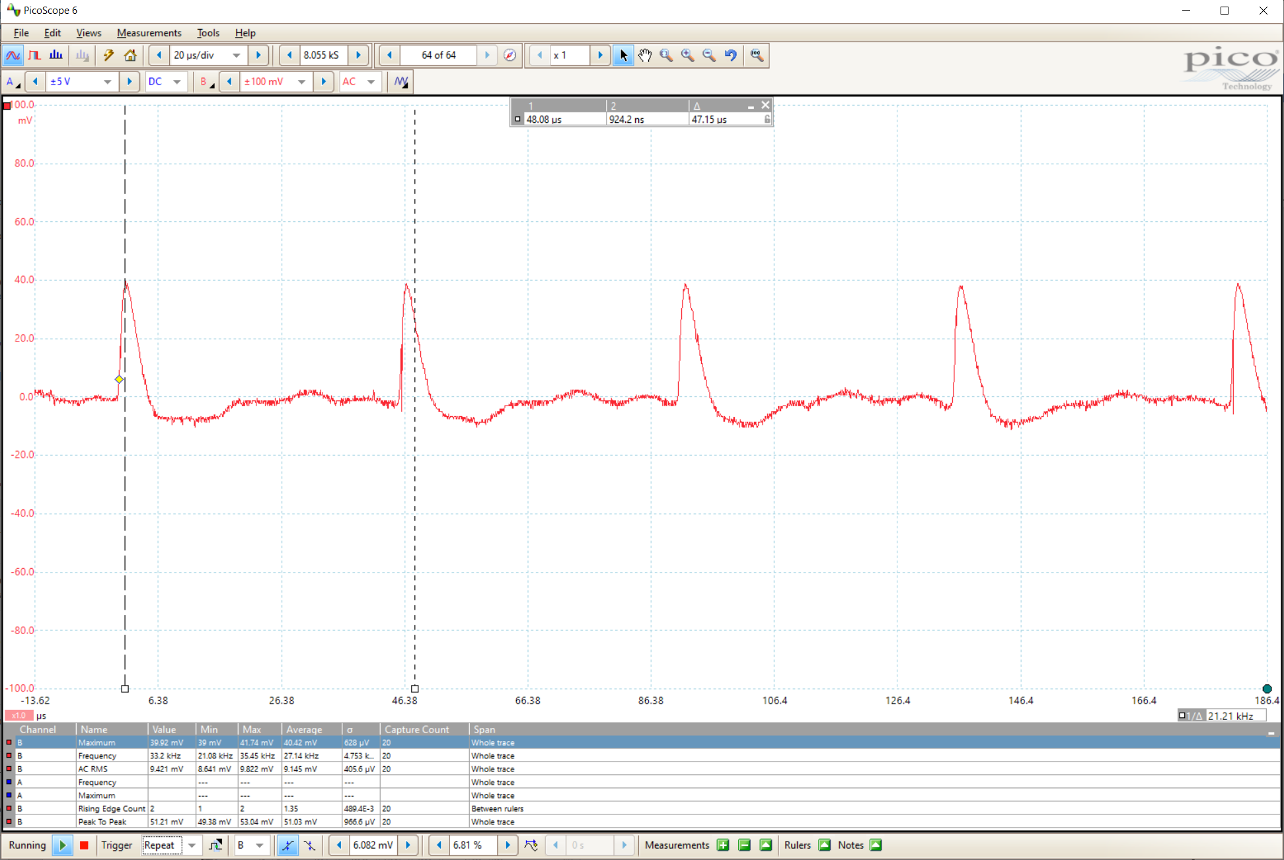
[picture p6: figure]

No ST-Link

LM

2675 5V

3.306V 0.63A

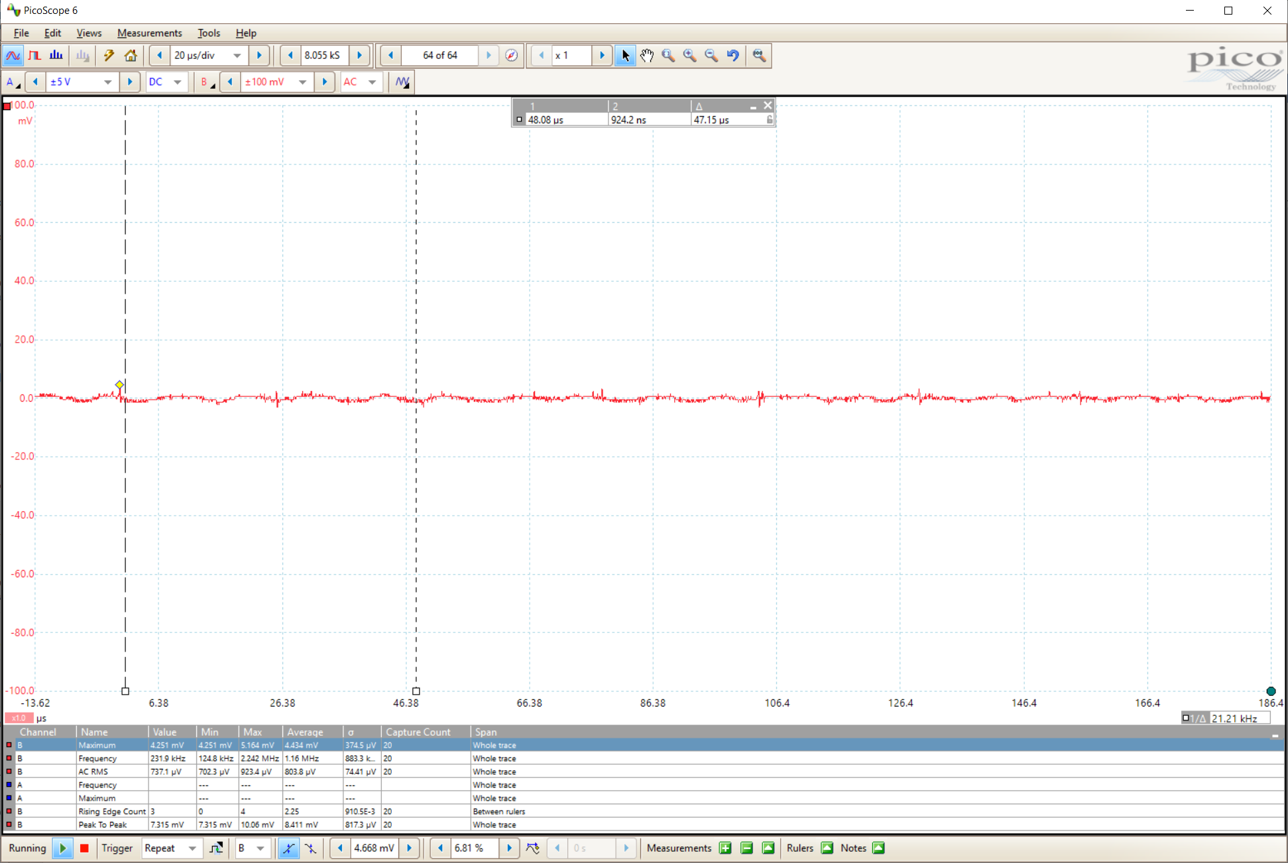
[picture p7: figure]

2675 3.3V

Digital Rail: 3.379V 0.062A

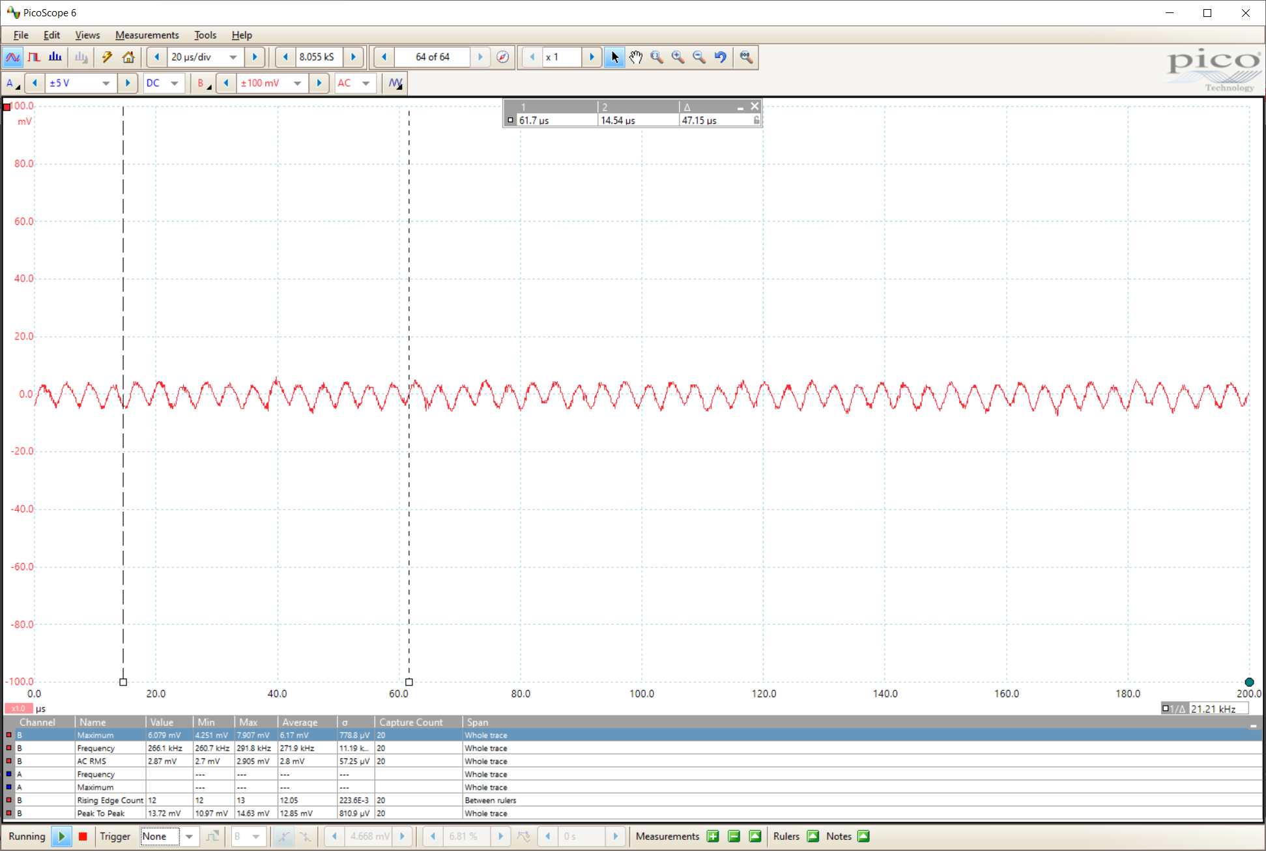
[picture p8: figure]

Analog Rail: 3.318V

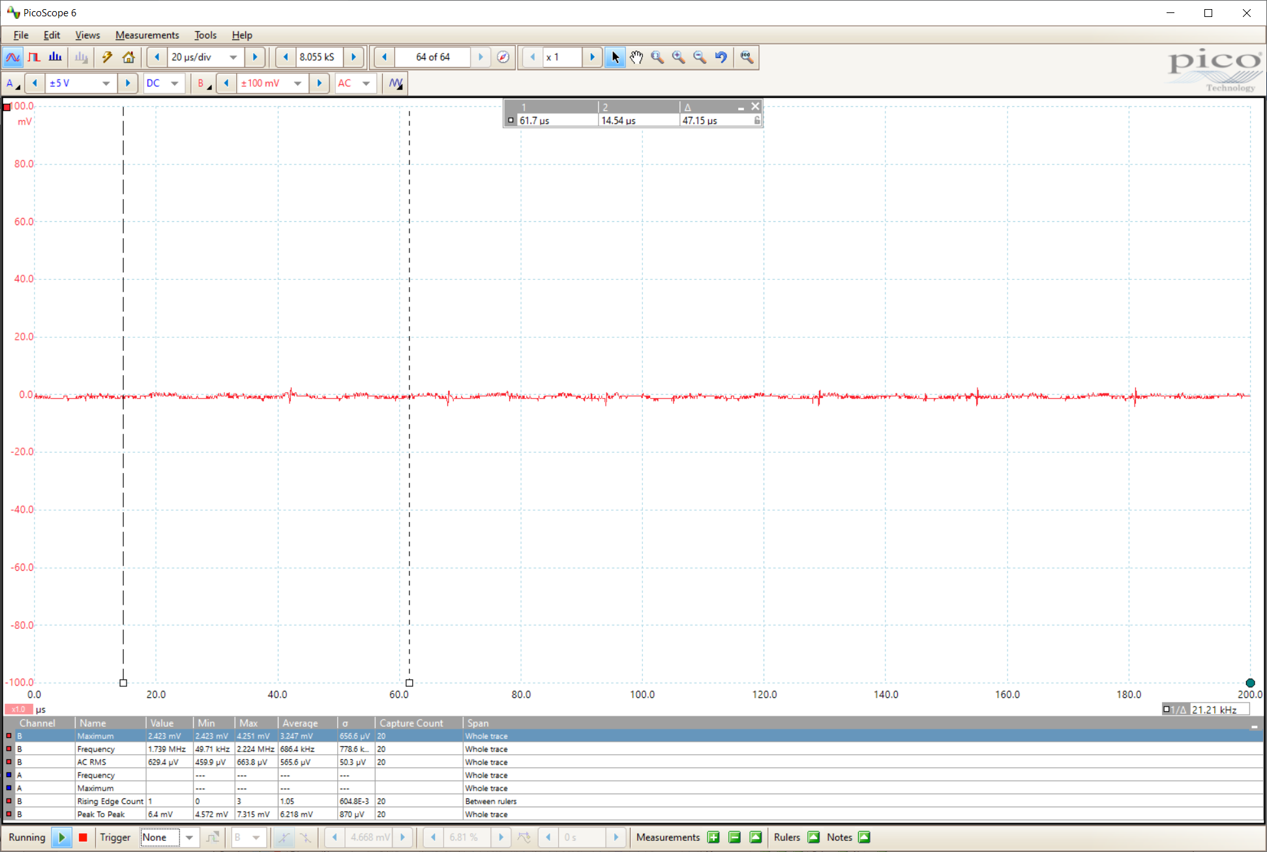
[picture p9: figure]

STM32H743 Original (No switching)

3.326V 0.132A

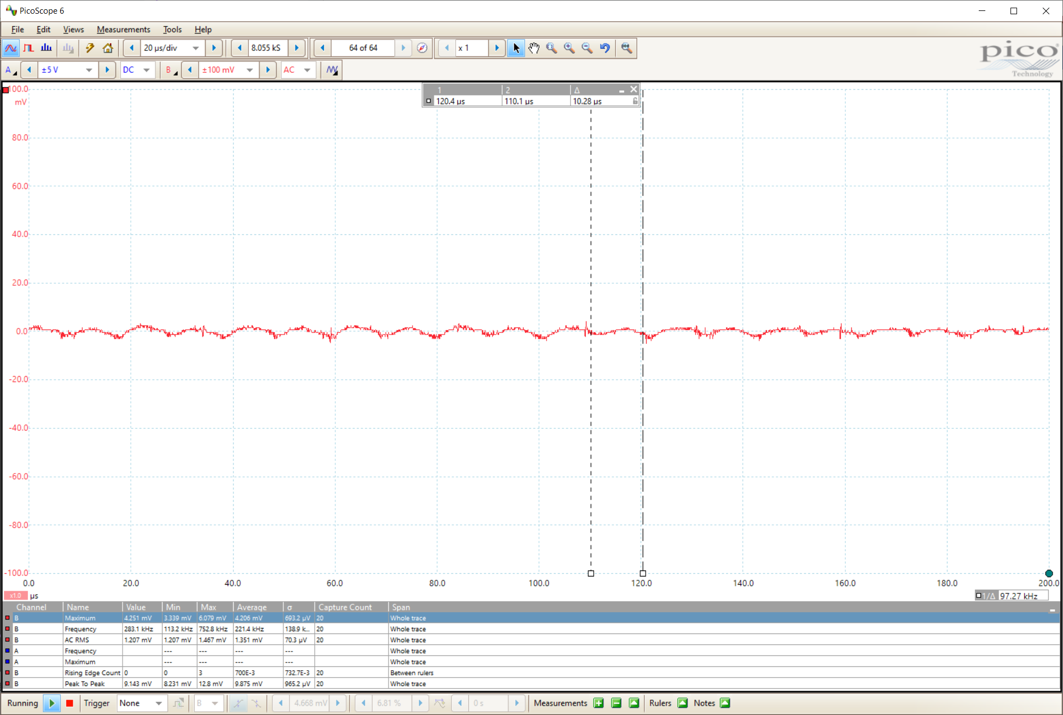
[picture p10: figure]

STM32H743 (LM2675)

3.307V 0.073A (@400MHz: 105mA)

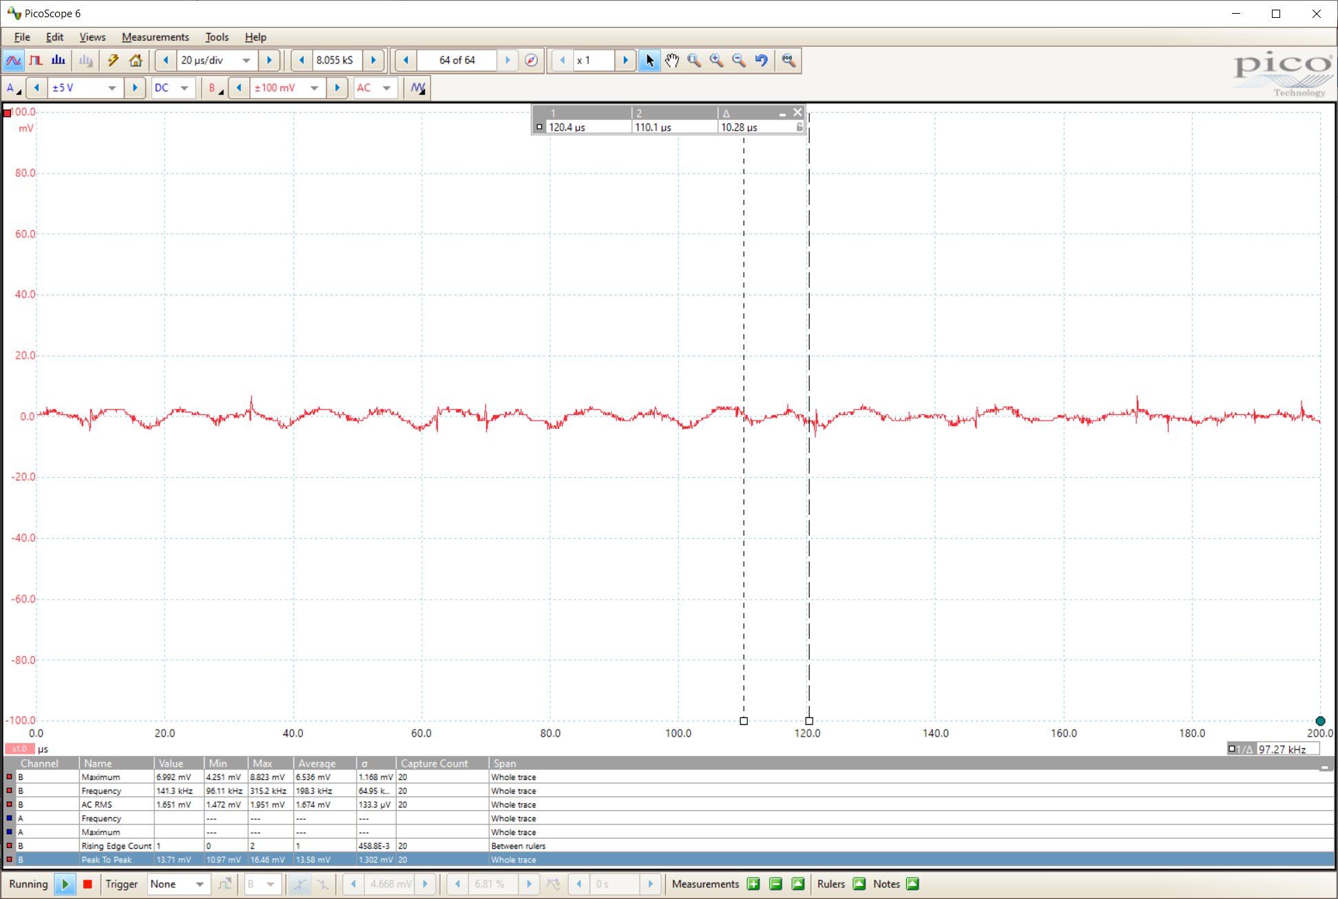
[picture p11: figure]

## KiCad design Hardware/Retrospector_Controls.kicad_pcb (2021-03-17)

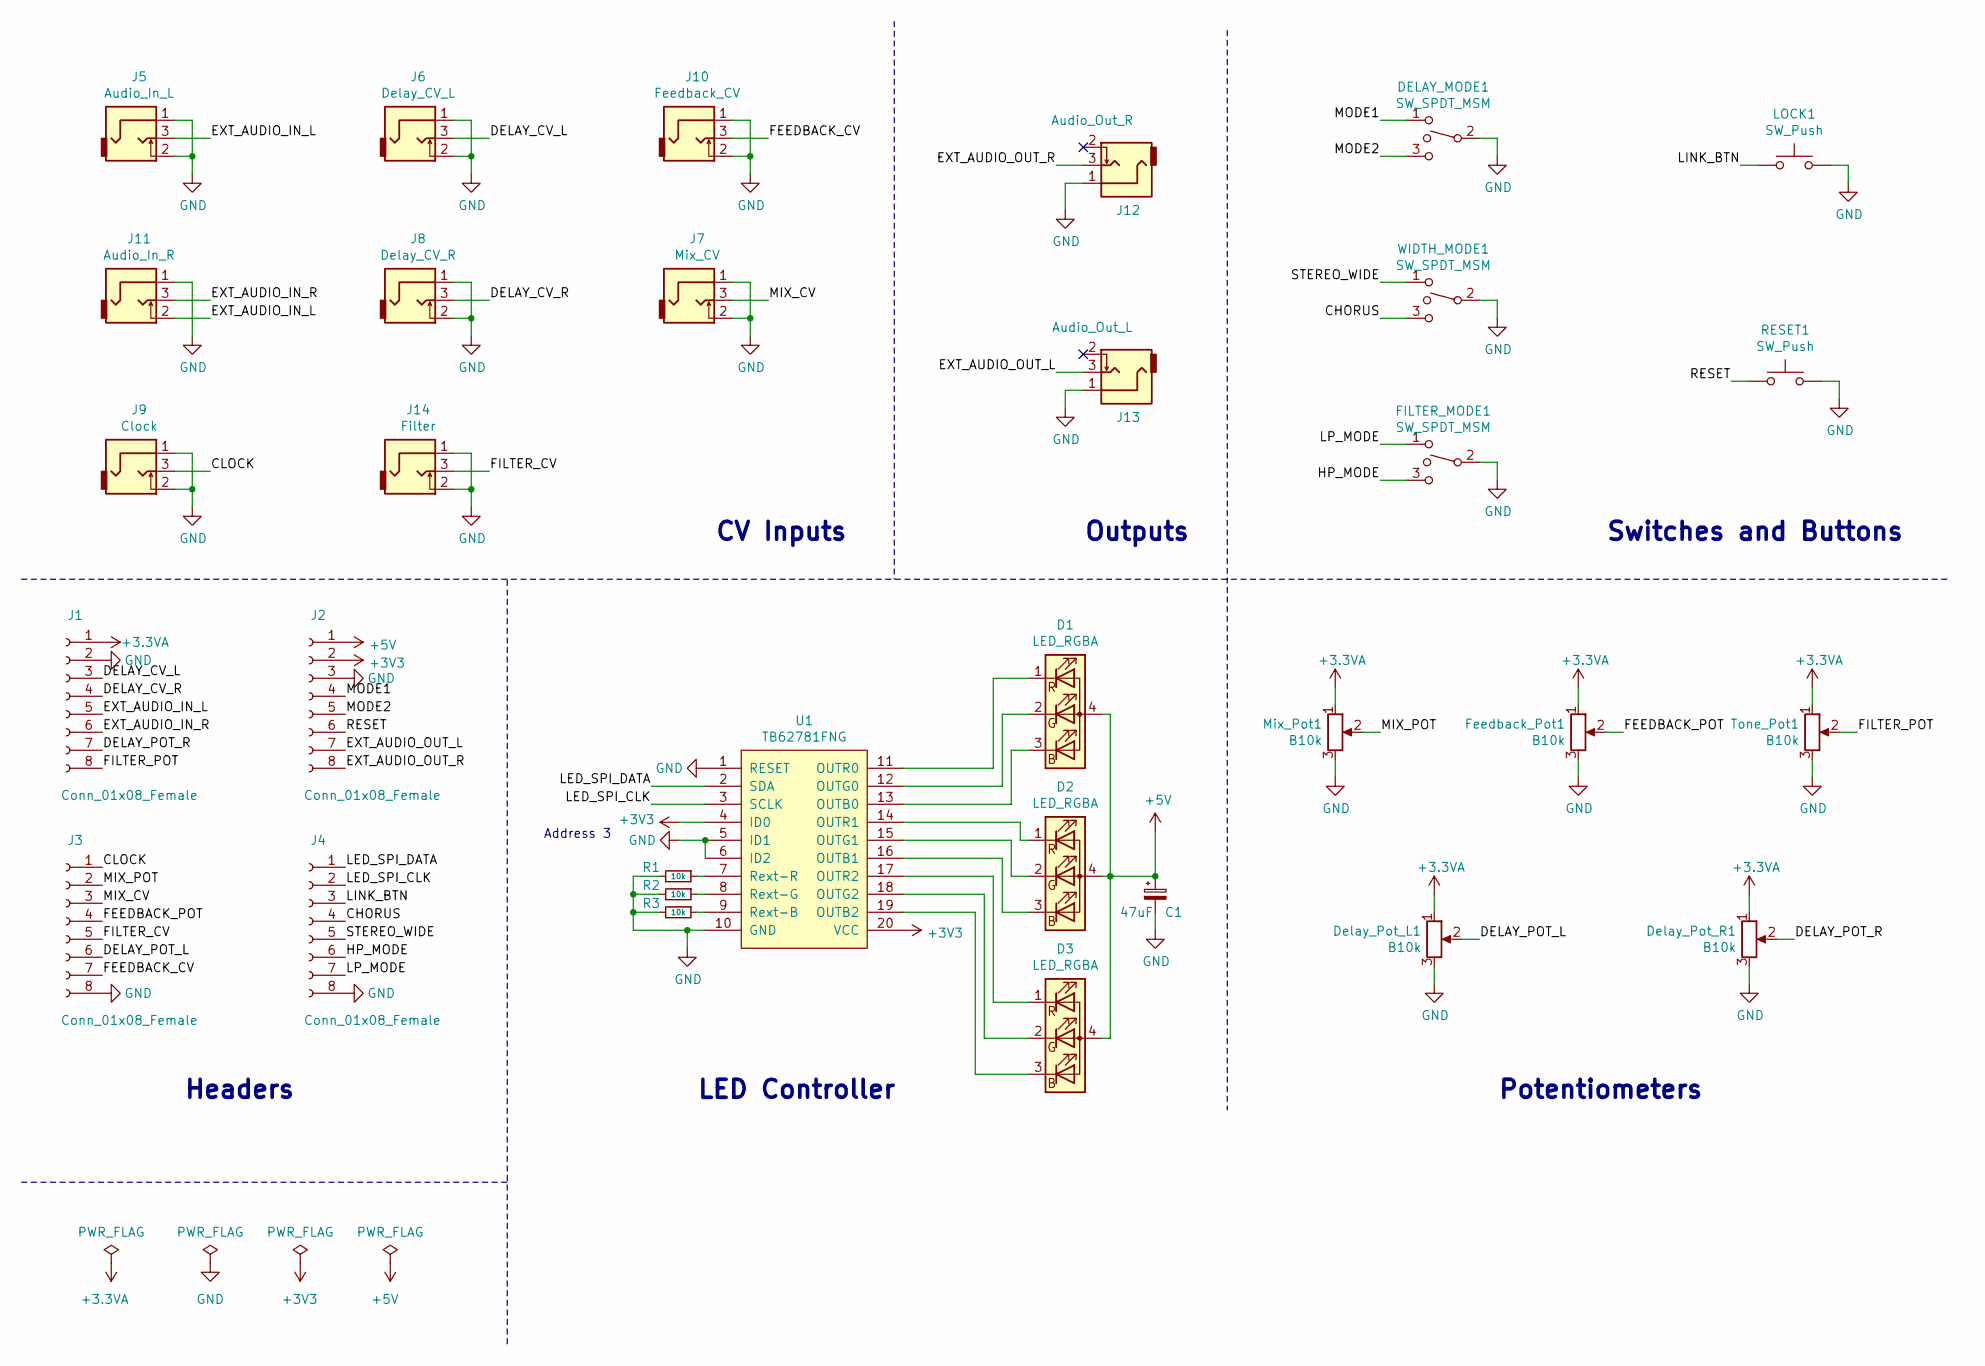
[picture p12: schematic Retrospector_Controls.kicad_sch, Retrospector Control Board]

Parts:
C1: 47uF; CP_Elec_5x5.8
D1, D2, D3: LED_RGBA; LED_RGB_PLCC4
DELAY_MODE1: SW_SPDT_MSM; SPDT_SubMiniature_Aligned
Delay_Pot_L1: B10k; Alpha_9mm_Potentiometer_Aligned
Delay_Pot_R1: B10k; Alpha_9mm_Potentiometer_Aligned
FILTER_MODE1: SW_SPDT_MSM; SPDT_SubMiniature_Aligned
Feedback_Pot1: B10k; Alpha_9mm_Potentiometer_Aligned
J1, J2, J3, J4: Conn_01x08_Female; Socket_Strip_Straight_1x08_Pitch2.54mm
J5: Audio_In_L; THONKICONN_hole
J6: Delay_CV_L; THONKICONN_hole
J7: Mix_CV; THONKICONN_hole
J8: Delay_CV_R; THONKICONN_hole
J9: Clock; THONKICONN_hole
J10: Feedback_CV; THONKICONN_hole
J11: Audio_In_R; THONKICONN_hole
J12: Audio_Out_R; THONKICONN_hole
J13: Audio_Out_L; THONKICONN_hole
J14: Filter; THONKICONN_hole
LOCK1: SW_Push; SW_PUSH_6mm_aligned
Mix_Pot1: B10k; Alpha_9mm_Potentiometer_Aligned
R1, R2, R3: 10k; R_0603_HandSoldering
RESET1: SW_Push; SW_PUSH_6mm_aligned
Tone_Pot1: B10k; Alpha_9mm_Potentiometer_Aligned
U1: TB62781FNG; SSOP-20_4.4x6.5mm_Pitch0.65mm
WIDTH_MODE1: SW_SPDT_MSM; SPDT_SubMiniature_Aligned

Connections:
+3.3VA: Delay_Pot_L1.1, Delay_Pot_R1.1, Feedback_Pot1.1, J1.1, Mix_Pot1.1, Tone_Pot1.1
+3V3: J2.2, U1.4 (ID0), U1.20 (VCC)
+5V: C1.1, D1.4 (A), D2.4 (A), D3.4 (A), J2.1
/CHORUS: J4.5, WIDTH_MODE1.1
/CLOCK: J3.1, J9.3
/DELAY_CV_L: J1.3, J6.3
/DELAY_CV_R: J1.4, J8.3
/DELAY_POT_L: Delay_Pot_L1.2, J3.6
/DELAY_POT_R: Delay_Pot_R1.2, J1.7
/EXT_AUDIO_IN_L: J1.5, J5.3, J11.2
/EXT_AUDIO_IN_R: J1.6, J11.3
/EXT_AUDIO_OUT_L: J2.7, J13.3
/EXT_AUDIO_OUT_R: J2.8, J12.3
/FEEDBACK_CV: J3.7, J10.3
/FEEDBACK_POT: Feedback_Pot1.2, J3.4
/FILTER_CV: J3.5, J14.3
/FILTER_POT: J1.8, Tone_Pot1.2
/HP_MODE: FILTER_MODE1.3, J4.6
/LED_SPI_CLK: J4.2, U1.3 (SCLK)
/LED_SPI_DATA: J4.1, U1.2 (SDA)
/LINK_BTN: J4.3, LOCK1.1
/LP_MODE: FILTER_MODE1.1, J4.7
/MIX_CV: J3.3, J7.3
/MIX_POT: J3.2, Mix_Pot1.2
/MODE1: DELAY_MODE1.1, J2.4
/MODE2: DELAY_MODE1.3, J2.5
/PINGPONG: J4.4, WIDTH_MODE1.3
/RESET: J2.6, RESET1.1
GND: C1.2, DELAY_MODE1.2, Delay_Pot_L1.3, Delay_Pot_R1.3, FILTER_MODE1.2, Feedback_Pot1.3, J1.2, J2.3, J3.8, J4.8, J5.1, J5.2, J6.1, J6.2, J7.1, J7.2, J8.1, J8.2, J9.1, J9.2, J10.1, J10.2, J11.1, J12.1, J13.1, J14.1, J14.2, LOCK1.2, Mix_Pot1.3, R1.2, R2.2, R3.2, RESET1.2, Tone_Pot1.3, U1.1 (RESET), U1.5 (ID1), U1.6 (ID2), U1.10 (GND), WIDTH_MODE1.2
unnamed: D1.1 (RK), U1.11 (OUTR0)
unnamed: D1.2 (GK), U1.12 (OUTG0)
unnamed: D1.3 (BK), U1.13 (OUTB0)
unnamed: D2.1 (RK), U1.14 (OUTR1)
unnamed: D2.2 (GK), U1.15 (OUTG1)
unnamed: D2.3 (BK), U1.16 (OUTB1)
unnamed: D3.1 (RK), U1.17 (OUTR2)
unnamed: D3.2 (GK), U1.18 (OUTG2)
unnamed: D3.3 (BK), U1.19 (OUTB2)
unnamed: R1.1, U1.7 (Rext-R)
unnamed: R2.1, U1.8 (Rext-G)
unnamed: R3.1, U1.9 (Rext-B)

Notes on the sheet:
Potentiometers
Address 3
LED Controller
Switches and Buttons
CV Inputs
Outputs
Headers

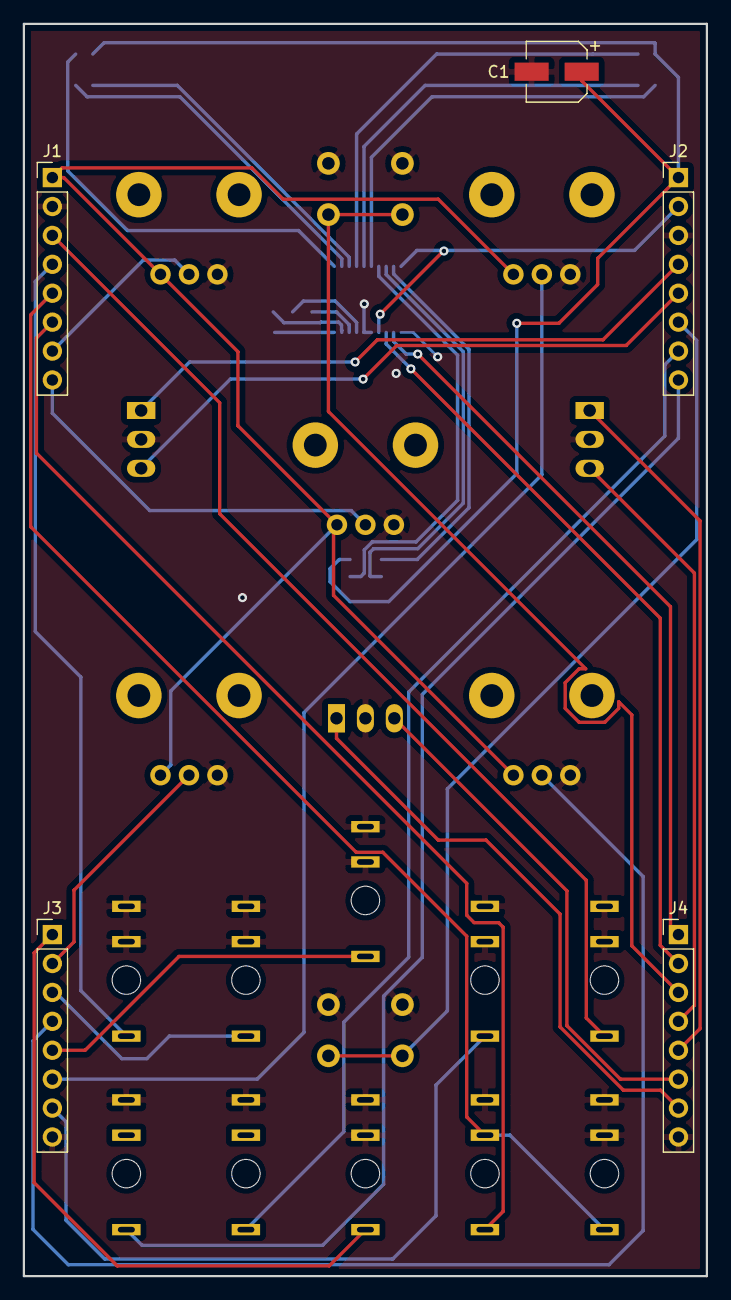
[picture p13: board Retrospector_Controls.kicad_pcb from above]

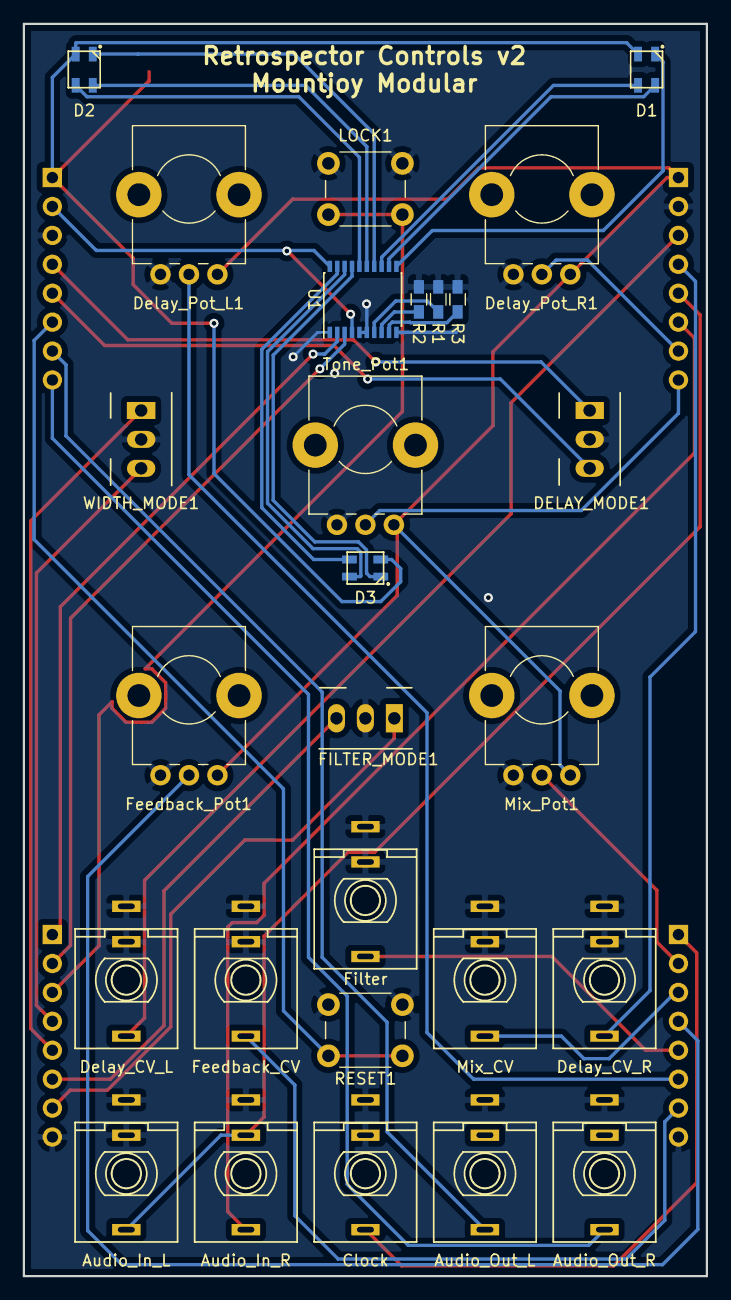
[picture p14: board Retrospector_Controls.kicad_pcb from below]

Board: 2 copper layers, 60.0 x 110.0 mm, 32 parts (27 on the bottom side), 41 nets.

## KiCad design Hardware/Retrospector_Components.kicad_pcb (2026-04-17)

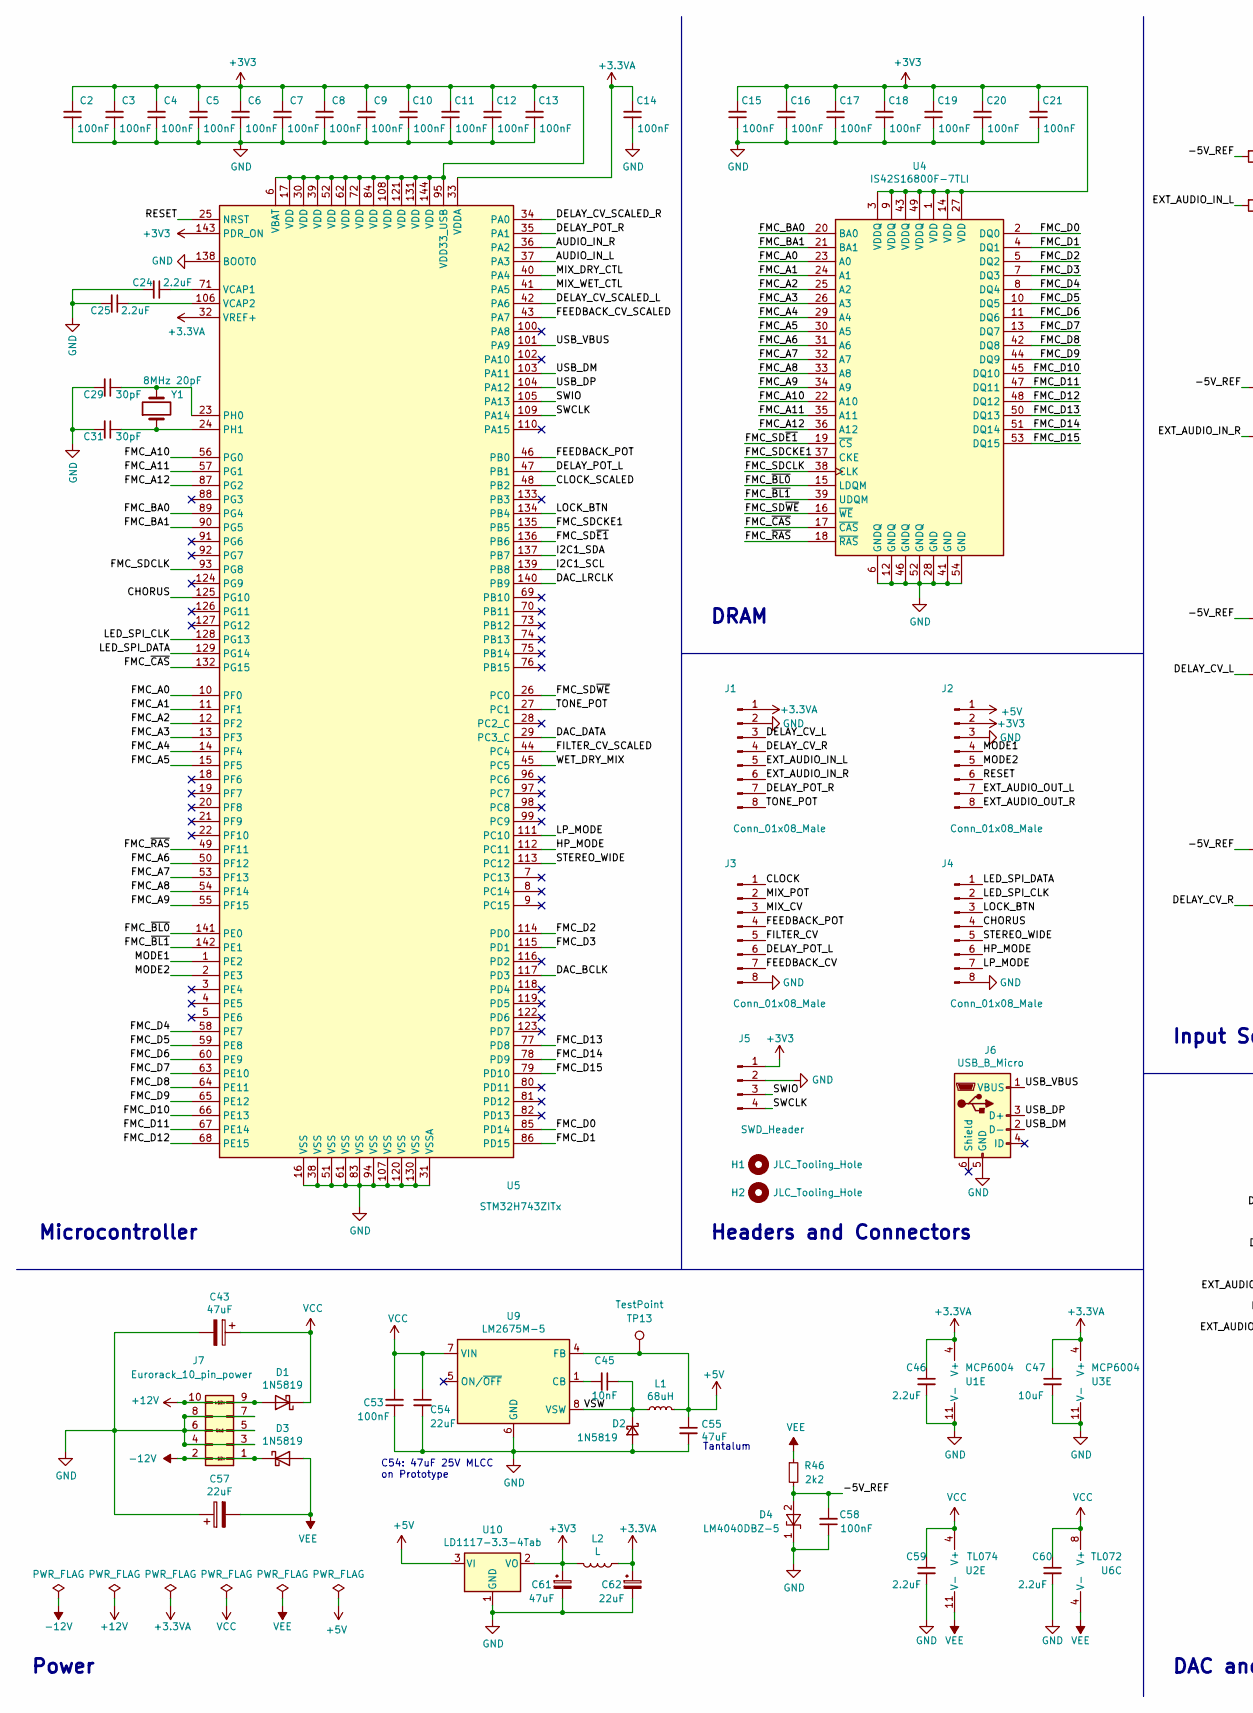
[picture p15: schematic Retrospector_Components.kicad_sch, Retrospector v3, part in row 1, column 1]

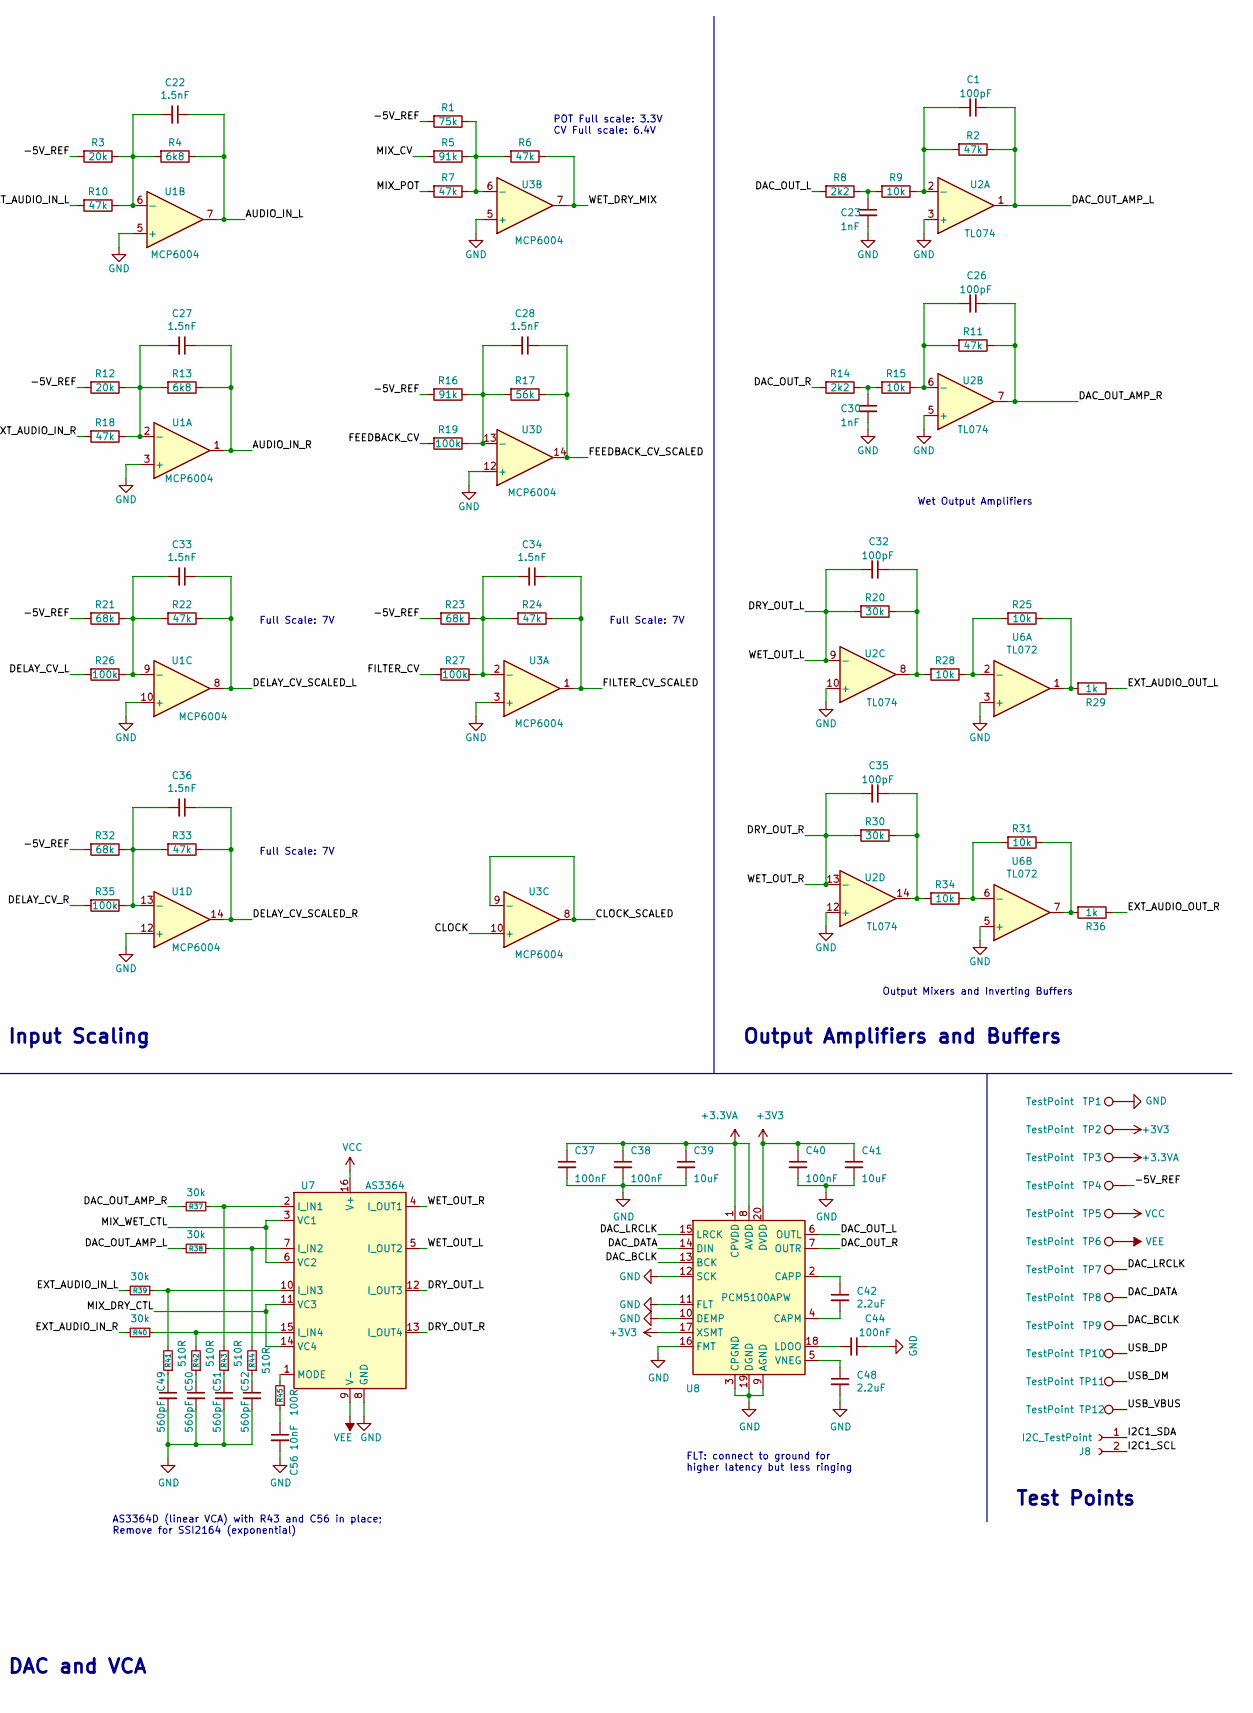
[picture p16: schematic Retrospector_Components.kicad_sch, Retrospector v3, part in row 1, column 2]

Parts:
C1, C26, C32, C35: 100pF; C_0603_HandSoldering; Part_Number C14858
C2, C3, C4, C5, C6, C7, C8, C9, C10, C11, C12, C13, C14, C15, C16, C17, C18, C19, C20, C21, C37, C38, C40, C44, C58: 100nF; C_0603_HandSoldering; Part_Number C14663
C22, C27, C28, C33, C34, C36: 1.5nF; C_0603_HandSoldering; Part_Number C1595
C23, C30: 1nF; C_0603_HandSoldering; Part_Number C1588
C24, C25, C42, C46, C48, C59, C60: 2.2uF; C_0603_HandSoldering; Part_Number C23630
C29, C31: 30pF; C_0603_HandSoldering; Part_Number C22397
C39, C41, C47: 10uF; C_0805; Part_Number C15850
C43, C61: 47uF; CP_Elec_5x5.8; Part_Number C134798
C45, C56: 10nF; C_0603_HandSoldering; Part_Number C57112
C49, C50, C51, C52: 560pF; C_0603_HandSoldering; Part_Number C84721
C53: 100nF; C_0603_HandSoldering
C54: 22uF; C_1210
C55: 47uF; C_1210
C57, C62: 22uF; CP_Elec_4x5.8; Part_Number C134793
D1, D2, D3: 1N5819; D_SOD-123; Part_Number C8598
D4: LM4040DBZ-5; SOT-23; Part_Number C156291
H1, H2: JLC_Tooling_Hole; JLC_SMT_Tooling_Hole
J1, J2, J3, J4: Conn_01x08_Male; Pin_Header_Straight_1x08_Pitch2.54mm
J5: SWD_Header; SWD_header
J6: USB_B_Micro; USB_Micro-B_Amphenol
J7: Eurorack_10_pin_power; Eurorack_10_pin_header
J8: I2C_TestPoint; Pin_Header_Straight_1x02_Pitch2.54mm
L1: 68uH; TDK_Inductor_6.9x7.2
L2: L; L_0805_HandSoldering; Part_Number C1046
R1: 75k; R_0603_HandSoldering; Part_Number C23242
R2, R6, R7, R10, R11, R18, R22, R24, R33: 47k; R_0603_HandSoldering; Part_Number C25819
R3, R12: 20k; R_0603_HandSoldering; Part_Number C4184
R4, R13: 6k8; R_0603_HandSoldering; Part_Number C23212
R5, R16: 91k; R_0603_HandSoldering; Part_Number C23265
R8, R14, R46: 2k2; R_0603_HandSoldering; Part_Number C4190
R9, R15, R25, R28, R31, R34: 10k; R_0603_HandSoldering; Part_Number C25804
R17: 56k; R_0603_HandSoldering; Part_Number C23206
R19, R26, R27, R35: 100k; R_0603_HandSoldering; Part_Number C25803
R20, R30, R37, R38, R39, R40: 30k; R_0603_HandSoldering; Part_Number C22984
R21, R23, R32: 68k; R_0603_HandSoldering; Part_Number C23231
R29, R36: 1k; R_0603_HandSoldering; Part_Number C21190
R41, R42, R43, R44: 510R; R_0603_HandSoldering; Part_Number C23193
R45: 100R; R_0603_HandSoldering; Part_Number C22775
TP1, TP2, TP3, TP4, TP5, TP6: TestPoint; 1.3mm_Test_Point
TP7, TP8, TP9, TP10, TP11, TP12, TP13: TestPoint; Measurement_Point_Square-SMD-Pad_Small
U1, U3: MCP6004; SOIC-14_N; Part_Number C116668
U2: TL074; SOIC-14_N; Part_Number C6964
U4: IS42S16800F-7TLI; TSOP-II-54_22.2x10.16mm_P0.8mm; Part_Number C91278
U5: STM32H743ZITx; LQFP-144_20x20mm_P0.5mm; Part_Number C114408
U6: TL072; SOIC-8_3.9x4.9mm_Pitch1.27mm; Part_Number C6961
U7: AS3364; SOIC-16_3.9x9.9mm_Pitch1.27mm
U8: PCM5100APW; SSOP-20_4.4x6.5mm_Pitch0.65mm_Round_Pads; Part_Number C131154
U9: LM2675M-5; SOIC-8_3.9x4.9mm_Pitch1.27mm; Part_Number C180371
U10: LD1117-3.3-4Tab; SOT-223-3_TabPin2
Y1: 8MHz 20pF; Crystal_SMD_5032-2pin_5.0x3.2mm_HandSoldering; Part_Number C115962

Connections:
+3.3VA: C14.2, C37.1, C38.1, C39.1, C46.1, C47.1, C62.1, J1.1, L2.1, TP3.1, U1.4 (V+), U3.4 (V+), U5.32 (VREF+), U5.33 (VDDA), U8.1 (CPVDD), U8.8 (AVDD)
+3V3: C2.2, C3.2, C4.2, C5.2, C6.2, C7.2, C8.2, C9.2, C10.2, C11.2, C12.2, C13.2, C15.2, C16.2, C17.2, C18.2, C19.2, C20.2, C21.2, C40.1, C41.1, C61.1, J2.2, J5.1, L2.2, TP2.1, U4.1 (VDD), U4.3 (VDDQ), U4.9 (VDDQ), U4.14 (VDD), U4.27 (VDD), U4.43 (VDDQ), U4.49 (VDDQ), U5.6 (VBAT), U5.17 (VDD), U5.30 (VDD), U5.39 (VDD), U5.52 (VDD), U5.62 (VDD), U5.72 (VDD), U5.84 (VDD), U5.95 (VDD33_USB), U5.108 (VDD), U5.121 (VDD), U5.131 (VDD), U5.143 (PDR_ON), U5.144 (VDD), U8.17 (XSMT), U8.20 (DVDD), U10.2 (VO)
+5V: C55.1, J2.1, L1.2, TP13.1, U9.4 (FB), U10.3 (VI)
+12V: D1.2 (A), J7.9, J7.10
-12V: D3.1 (K), J7.1, J7.2
/-5V_REF: C58.2, D4.2 (A), R1.2, R3.2, R12.2, R16.2, R21.2, R23.2, R32.2, R46.2, TP4.1
/AUDIO_IN_L: C22.1, R4.1, U1.7, U5.37 (PA3)
/AUDIO_IN_R: C27.1, R13.1, U1.1, U5.36 (PA2)
/CHORUS: J4.4, U5.125 (PG10)
/CLOCK: J3.1, U3.10 (+)
/CLOCK_SCALED: U3.8, U3.9 (-), U5.48 (PB2)
/DAC_BCLK: TP9.1, U5.117 (PD3), U8.13 (BCK)
/DAC_DATA: TP8.1, U5.29 (PC3_C), U8.14 (DIN)
/DAC_LRCLK: TP7.1, U5.140 (PB9), U8.15 (LRCK)
/DAC_OUT_AMP_L: C1.1, R2.1, R38.2, U2.1
/DAC_OUT_AMP_R: C26.1, R11.1, R37.2, U2.7
/DAC_OUT_L: R8.2, U8.6 (OUTL)
/DAC_OUT_R: R14.2, U8.7 (OUTR)
/DELAY_CV_L: J1.3, R26.2
/DELAY_CV_R: J1.4, R35.2
/DELAY_CV_SCALED_L: C33.1, R22.1, U1.8, U5.42 (PA6)
/DELAY_CV_SCALED_R: C36.1, R33.1, U1.14, U5.34 (PA0)
/DELAY_POT_L: J3.6, U5.47 (PB1)
/DELAY_POT_R: J1.7, U5.35 (PA1)
/DRY_OUT_L: C32.2, R20.2, U2.9 (-), U7.5 (I_OUT2), U7.12 (I_OUT3)
/DRY_OUT_R: C35.2, R30.2, U2.13 (-), U7.4 (I_OUT1), U7.13 (I_OUT4)
/EXT_AUDIO_IN_L: J1.5, R10.2, R39.2
/EXT_AUDIO_IN_R: J1.6, R18.2, R40.2
/EXT_AUDIO_OUT_L: J2.7, R29.1
/EXT_AUDIO_OUT_R: J2.8, R36.1
/FEEDBACK_CV: J3.7, R19.2
/FEEDBACK_CV_SCALED: C28.1, R17.1, U3.14, U5.43 (PA7)
/FEEDBACK_POT: J3.4, U5.46 (PB0)
/FILTER_CV: J3.5, R27.2
/FILTER_CV_SCALED: C34.1, R24.1, U3.1, U5.44 (PC4)
/FMC_A0: U4.23 (A0), U5.10 (PF0)
/FMC_A1: U4.24 (A1), U5.11 (PF1)
/FMC_A2: U4.25 (A2), U5.12 (PF2)
/FMC_A3: U4.26 (A3), U5.13 (PF3)
/FMC_A4: U4.29 (A4), U5.14 (PF4)
/FMC_A5: U4.30 (A5), U5.15 (PF5)
/FMC_A6: U4.31 (A6), U5.50 (PF12)
/FMC_A7: U4.32 (A7), U5.53 (PF13)
/FMC_A8: U4.33 (A8), U5.54 (PF14)
/FMC_A9: U4.34 (A9), U5.55 (PF15)
/FMC_A10: U4.22 (A10), U5.56 (PG0)
/FMC_A11: U4.35 (A11), U5.57 (PG1)
/FMC_A12: U4.36 (A12), U5.87 (PG2)
/FMC_BA0: U4.20 (BA0), U5.89 (PG4)
/FMC_BA1: U4.21 (BA1), U5.90 (PG5)
/FMC_D0: U4.2 (DQ0), U5.85 (PD14)
/FMC_D1: U4.4 (DQ1), U5.86 (PD15)
/FMC_D2: U4.5 (DQ2), U5.114 (PD0)
/FMC_D3: U4.7 (DQ3), U5.115 (PD1)
/FMC_D4: U4.8 (DQ4), U5.58 (PE7)
/FMC_D5: U4.10 (DQ5), U5.59 (PE8)
/FMC_D6: U4.11 (DQ6), U5.60 (PE9)
/FMC_D7: U4.13 (DQ7), U5.63 (PE10)
/FMC_D8: U4.42 (DQ8), U5.64 (PE11)
/FMC_D9: U4.44 (DQ9), U5.65 (PE12)
/FMC_D10: U4.45 (DQ10), U5.66 (PE13)
/FMC_D11: U4.47 (DQ11), U5.67 (PE14)
/FMC_D12: U4.48 (DQ12), U5.68 (PE15)
/FMC_D13: U4.50 (DQ13), U5.77 (PD8)
/FMC_D14: U4.51 (DQ14), U5.78 (PD9)
/FMC_D15: U4.53 (DQ15), U5.79 (PD10)
/FMC_SDCKE1: U4.37 (CKE), U5.135 (PB5)
/FMC_SDCLK: U4.38 (CLK), U5.93 (PG8)
/FMC_SD~E1: U4.19 (~CS), U5.136 (PB6)
/FMC_SD~WE: U4.16 (~WE), U5.26 (PC0)
/FMC_~BL0: U4.15 (LDQM), U5.141 (PE0)
/FMC_~BL1: U4.39 (UDQM), U5.142 (PE1)
/FMC_~CAS: U4.17 (~CAS), U5.132 (PG15)
/FMC_~RAS: U4.18 (~RAS), U5.49 (PF11)
/HP_MODE: J4.6, U5.112 (PC11)
/I2C1_SCL: J8.2, U5.139 (PB8)
/I2C1_SDA: J8.1, U5.137 (PB7)
/LED_SPI_CLK: J4.2, U5.128 (PG13)
/LED_SPI_DATA: J4.1, U5.129 (PG14)
/LOCK_BTN: J4.3, U5.134 (PB4)
/LP_MODE: J4.7, U5.111 (PC10)
/MIX_CV: J3.3, R5.2
/MIX_DRY_CTL: U5.40 (PA4), U7.11 (VC3), U7.14 (VC4)
/MIX_POT: J3.2, R7.2
/MIX_WET_CTL: U5.41 (PA5), U7.3 (VC1), U7.6 (VC2)
/MODE1: J2.4, U5.1 (PE2)
/MODE2: J2.5, U5.2 (PE3)
/RESET: J2.6, U5.25 (NRST)
/STEREO_WIDE: J4.5, U5.113 (PC12)
/SWCLK: J5.4, U5.109 (PA14)
/SWIO: J5.3, U5.105 (PA13)
/TONE_POT: J1.8, U5.27 (PC1)
/USB_DM: J6.2 (D-), TP11.1, U5.103 (PA11)
/USB_DP: J6.3 (D+), TP10.1, U5.104 (PA12)
/USB_VBUS: J6.1 (VBUS), TP12.1, U5.101 (PA9)
/VSW: C45.1, D2.1 (K), L1.1, U9.8 (VSW)
/WET_DRY_MIX: R6.1, U3.7, U5.45 (PC5)
GND: C2.1, C3.1, C4.1, C5.1, C6.1, C7.1, C8.1, C9.1, C10.1, C11.1, C12.1, C13.1, C14.1, C15.1, C16.1, C17.1, C18.1, C19.1, C20.1, C21.1, C23.2, C24.2, C25.2, C29.2, C30.2, C31.2, C37.2, C38.2, C39.2, C40.2, C41.2, C43.2, C44.1, C46.2, C47.2, C48.2, C49.2, C50.2, C51.2, C52.2, C53.1, C54.2, C55.2, C56.2, C57.1, C58.1, C59.2, C60.2, C61.2, C62.2, D2.2 (A), D4.1 (K), J1.2, J2.3, J3.8, J4.8, J5.2, J6.5 (GND), J7.3, J7.4, J7.5, J7.6, J7.7, J7.8, TP1.1, U1.3 (+), U1.5 (+), U1.10 (+), U1.11 (V-), U1.12 (+), U2.3 (+), U2.5 (+), U2.10 (+), U2.12 (+), U3.3 (+), U3.5 (+), U3.11 (V-), U3.12 (+), U4.6 (GNDQ), U4.12 (GNDQ), U4.28 (GND), U4.41 (GND), U4.46 (GNDQ), U4.52 (GNDQ), U4.54 (GND), U5.16 (VSS), U5.31 (VSSA), U5.38 (VSS), U5.51 (VSS), U5.61 (VSS), U5.83 (VSS), U5.94 (VSS), U5.107 (VSS), U5.120 (VSS), U5.130 (VSS), U5.138 (BOOT0), U6.3 (+), U6.5 (+), U7.8 (GND), U8.3 (CPGND), U8.9 (AGND), U8.10 (DEMP), U8.11 (FLT), U8.12 (SCK), U8.16 (FMT), U8.19 (DGND), U9.6 (GND), U10.1 (GND)
unnamed: C1.2, R2.2, R9.1, U2.2 (-)
unnamed: C22.2, R3.1, R4.2, R10.1, U1.6 (-)
unnamed: C23.1, R8.1, R9.2
unnamed: C24.1, U5.71 (VCAP1)
unnamed: C25.1, U5.106 (VCAP2)
unnamed: C26.2, R11.2, R15.1, U2.6 (-)
unnamed: C27.2, R12.1, R13.2, R18.1, U1.2 (-)
unnamed: C28.2, R16.1, R17.2, R19.1, U3.13 (-)
unnamed: C29.1, U5.23 (PH0), Y1.2
unnamed: C30.1, R14.1, R15.2
unnamed: C31.1, U5.24 (PH1), Y1.1
unnamed: C32.1, R20.1, R28.2, U2.8
unnamed: C33.2, R21.1, R22.2, R26.1, U1.9 (-)
unnamed: C34.2, R23.1, R24.2, R27.1, U3.2 (-)
unnamed: C35.1, R30.1, R34.2, U2.14
unnamed: C36.2, R32.1, R33.2, R35.1, U1.13 (-)
unnamed: C42.1, U8.2 (CAPP)
unnamed: C42.2, U8.4 (CAPM)
unnamed: C44.2, U8.18 (LDOO)
unnamed: C45.2, U9.1 (CB)
unnamed: C48.1, U8.5 (VNEG)
unnamed: C49.1, R41.1
unnamed: C50.1, R42.1
unnamed: C51.1, R43.1
unnamed: C52.1, R44.1
unnamed: C56.1, R45.1
unnamed: R1.1, R5.1, R6.2, R7.1, U3.6 (-)
unnamed: R25.1, R29.2, U6.1
unnamed: R25.2, R28.1, U6.2 (-)
unnamed: R31.1, R36.2, U6.7
unnamed: R31.2, R34.1, U6.6 (-)
unnamed: R37.1, R43.2, U7.2 (I_IN1)
unnamed: R38.1, R44.2, U7.7 (I_IN2)
unnamed: R39.1, R41.2, U7.10 (I_IN3)
unnamed: R40.1, R42.2, U7.15 (I_IN4)
unnamed: R45.2, U7.1 (MODE)
VCC: C43.1, C53.2, C54.1, C59.1, C60.1, D1.1 (K), TP5.1, U2.4 (V+), U6.8 (V+), U7.16 (V+), U9.7 (VIN)
VEE: C57.2, D3.2 (A), R46.1, TP6.1, U2.11 (V-), U6.4 (V-), U7.9 (V-)

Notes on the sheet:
DRAM
C54: 47uF 25V MLCC on Prototype
Input Scaling
Full Scale: 7V
Microcontroller
Headers and Connectors
Wet Output Amplifiers
POT Full scale: 3.3V CV Full scale: 6.4V
Tantalum
Power
AS3364D (linear VCA) with R43 and C56 in place; Remove for SSI2164 (exponential)
DAC and VCA
Output Mixers and Inverting Buffers
Output Amplifiers and Buffers
FLT: connect to ground for higher latency but less ringing
Test Points

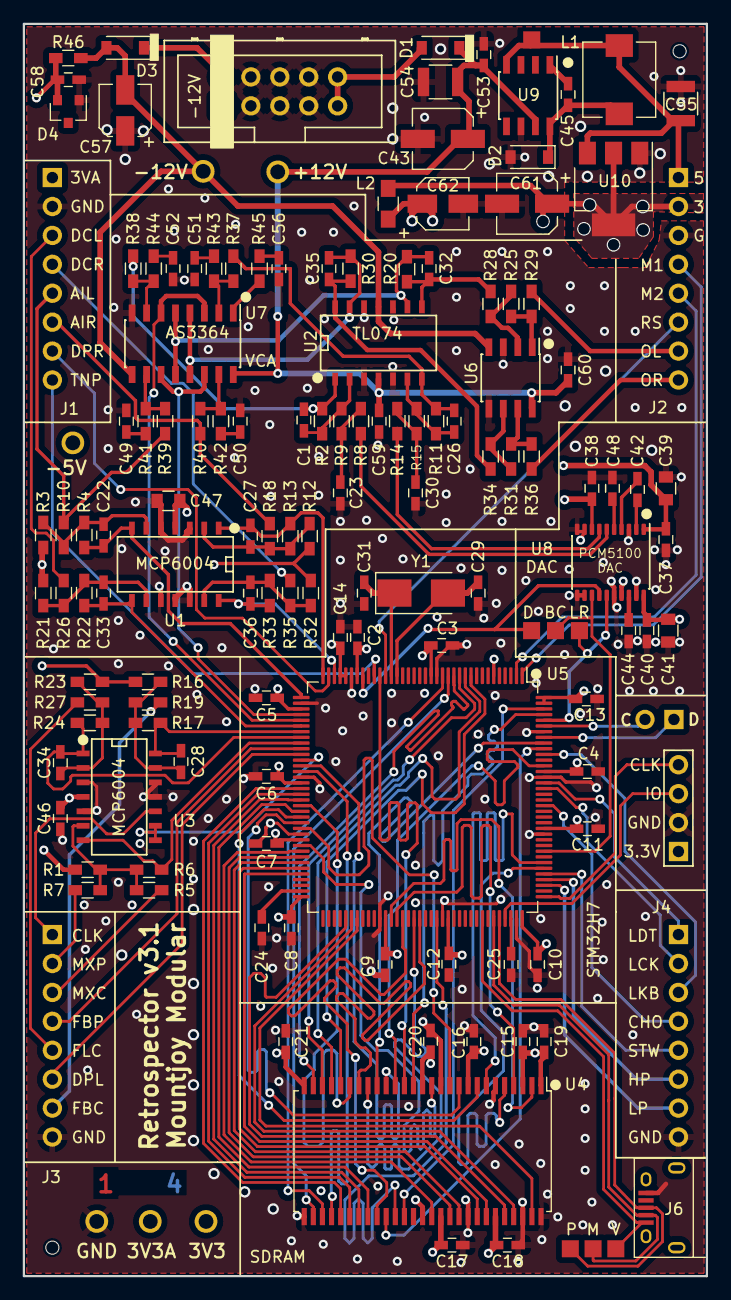
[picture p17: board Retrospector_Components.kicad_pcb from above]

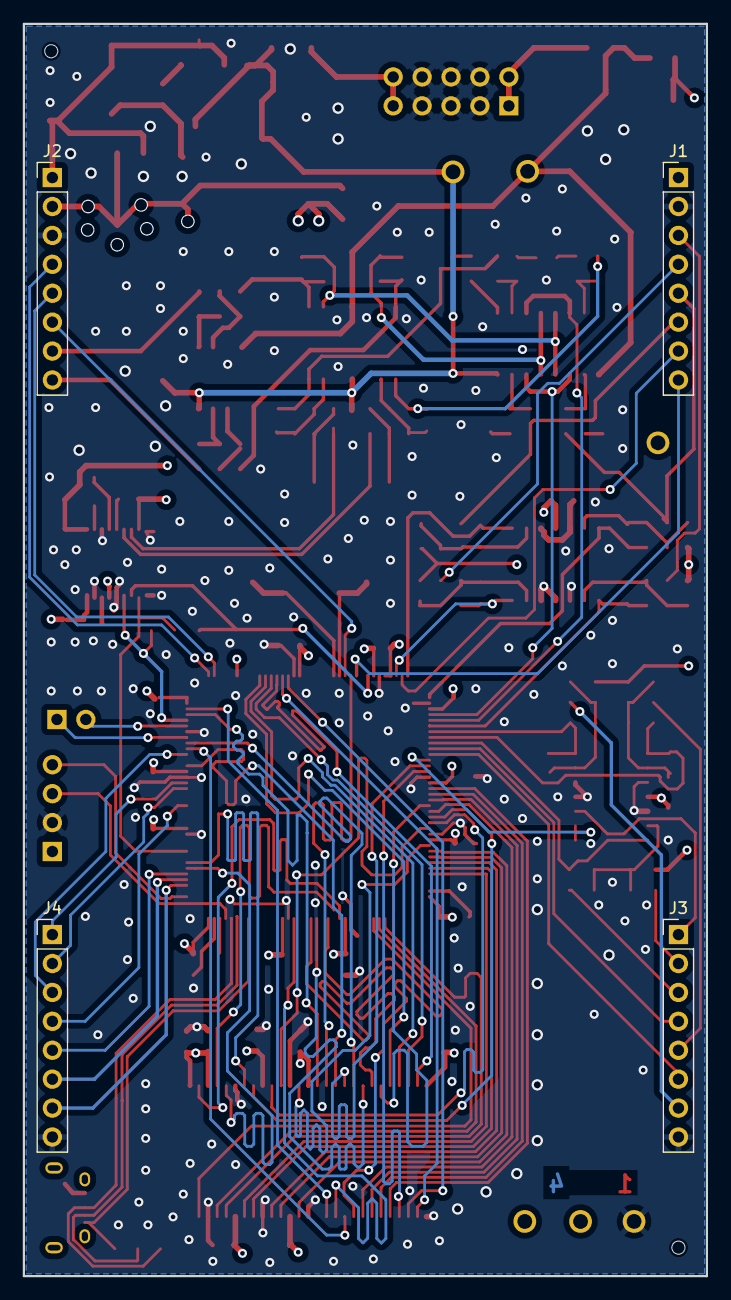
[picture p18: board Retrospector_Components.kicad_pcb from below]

Board: 4 copper layers, 60.0 x 110.0 mm, 149 parts (4 on the bottom side), 136 nets.

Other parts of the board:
4_Layer_Marker: 4_Layer_Markers

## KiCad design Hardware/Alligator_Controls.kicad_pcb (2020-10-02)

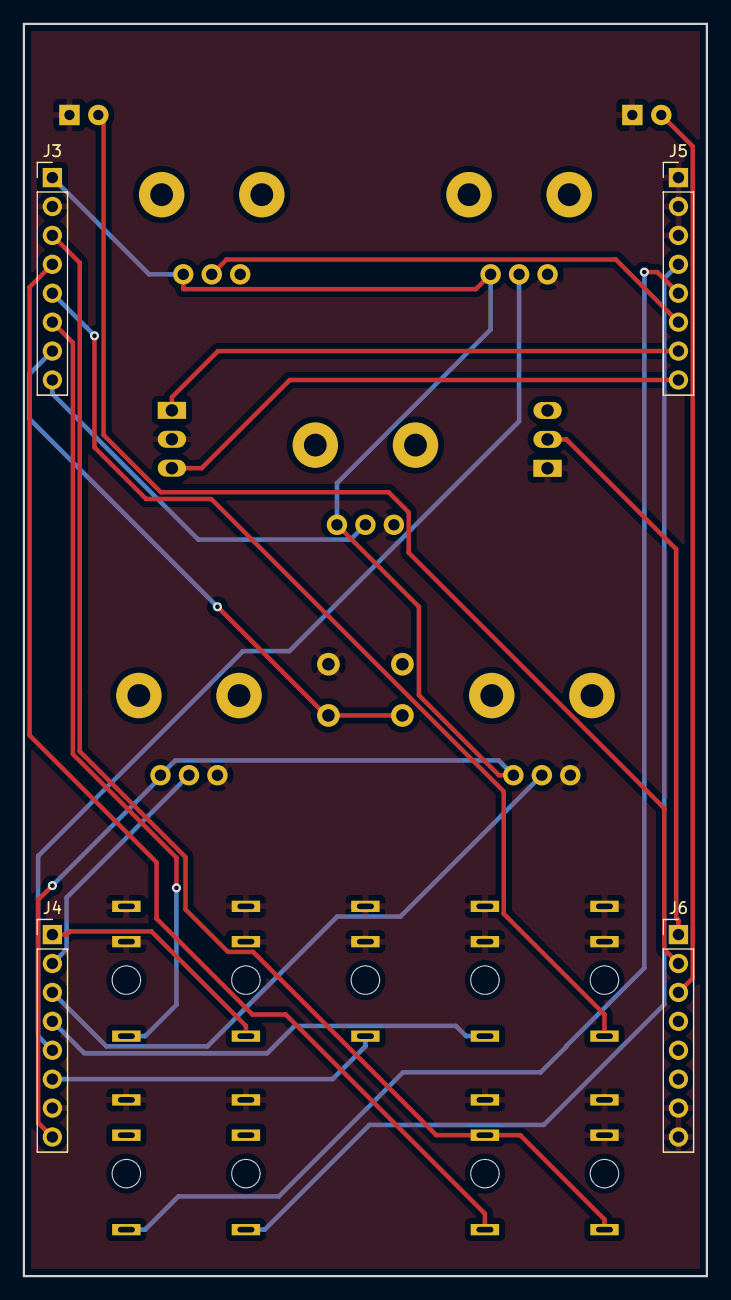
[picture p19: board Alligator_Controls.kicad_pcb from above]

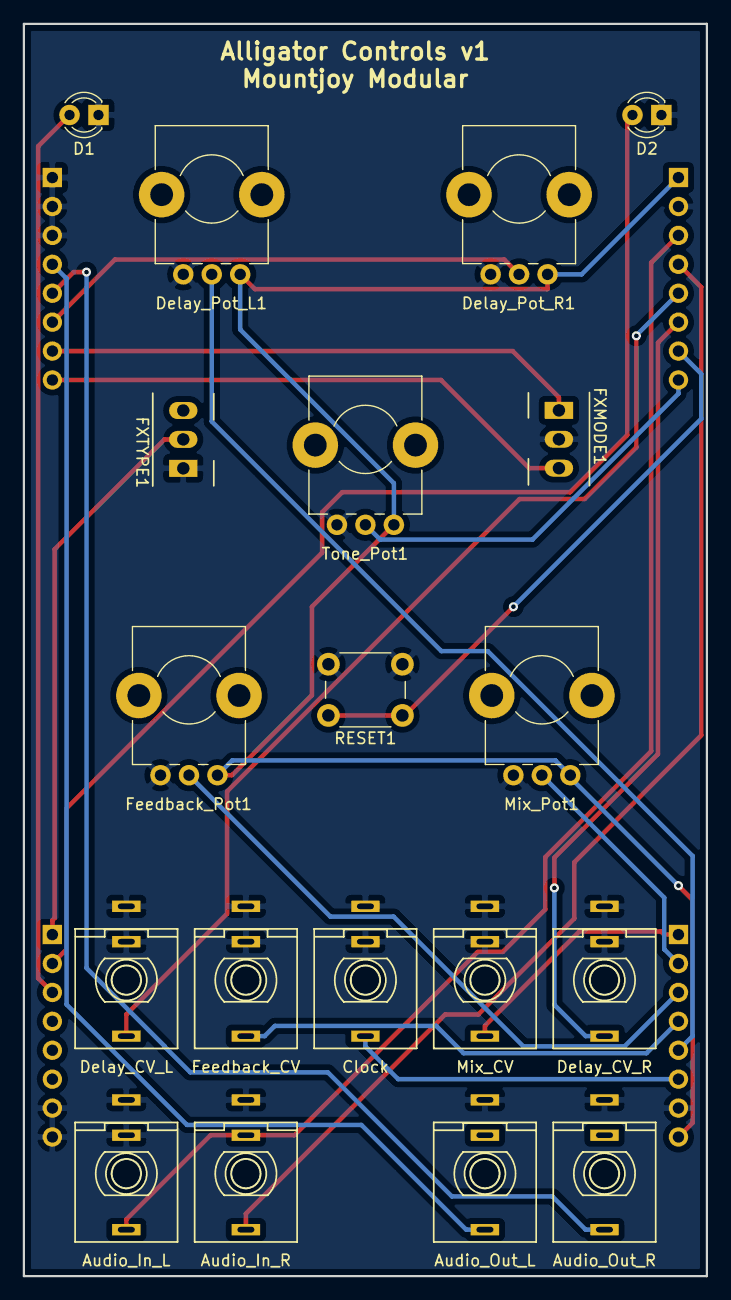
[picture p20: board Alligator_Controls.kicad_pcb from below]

Board: 2 copper layers, 60.0 x 110.0 mm, 23 parts (19 on the bottom side), 22 nets.

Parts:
D1, D2: LED; LED_D3.0mm
Delay_Pot_L1: A10k; Alpha_9mm_Potentiometer
Delay_Pot_R1: A10k; Alpha_9mm_Potentiometer
FXMODE1: SW_SPDT_MSM; SPDTSubMiniature
FXTYPE1: SW_SPST; SPDTSubMiniature
Feedback_Pot1: A10k; Alpha_9mm_Potentiometer
J1: Audio_In_L; THONKICONN_hole
J2: Delay_CV_L; THONKICONN_hole
J3, J4, J5, J6: Conn_01x08_Female; Socket_Strip_Straight_1x08_Pitch2.54mm
J7: Mix_CV; THONKICONN_hole
J8: Delay_CV_R; THONKICONN_hole
J9: Clock; THONKICONN_hole
J10: Feedback_CV; THONKICONN_hole
J11: Audio_In_R; THONKICONN_hole
J12: Audio_Out_R; THONKICONN_hole
J13: Audio_Out_L; THONKICONN_hole
Mix_Pot1: A10k; Alpha_9mm_Potentiometer
RESET1: SW_Push; SW_PUSH_6mm
Tone_Pot1: A10k; Alpha_9mm_Potentiometer

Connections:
+3.3VA: Delay_Pot_L1.1, Delay_Pot_R1.1, Feedback_Pot1.1, J3.1, J4.8, Mix_Pot1.1, Tone_Pot1.1
/CLOCK: J4.6, J9.3
/DELAY_CHORUS: FXTYPE1.2, J6.1
/DELAY_CV_L: J2.3, J3.5
/DELAY_CV_R: J3.6, J8.3
/DELAY_POT_L: Delay_Pot_L1.2, J4.5
/DELAY_POT_R: Delay_Pot_R1.2, J5.6
/EXT_AUDIO_IN_L: J1.3, J3.3, J11.2
/EXT_AUDIO_IN_R: J3.4, J11.3
/EXT_AUDIO_OUT_L: J5.4, J13.3
/EXT_AUDIO_OUT_R: J5.5, J12.3
/FEEDBACK_CV: J4.4, J10.3
/FEEDBACK_POT: Feedback_Pot1.2, J4.3
/LED1: D1.2, J6.3
/LED2: D2.2, J6.2
/MIX_CV: J4.1, J7.3
/MIX_POT: J4.2, Mix_Pot1.2
/MODE1: FXMODE1.1, J5.7
/MODE2: FXMODE1.3, J5.8
/RESET: J3.7, RESET1.1
/TONE_POT: J3.8, Tone_Pot1.2
GND: D1.1, D2.1, Delay_Pot_L1.3, Delay_Pot_R1.3, FXMODE1.2, FXTYPE1.1, Feedback_Pot1.3, J1.1, J1.2, J2.1, J2.2, J3.2, J4.7, J5.1, J5.2, J5.3, J6.7, J6.8, J7.1, J7.2, J8.1, J8.2, J9.1, J9.2, J10.1, J10.2, J11.1, J12.1, J13.1, Mix_Pot1.3, RESET1.2, Tone_Pot1.3

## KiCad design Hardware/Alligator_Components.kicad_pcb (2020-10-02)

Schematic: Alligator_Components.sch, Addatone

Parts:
C1, C5, C7, C8, C9, C10, C11, C12, C13, C14, C15, C16, C17, C19, C20, C21, C24, C25, C26, C35, C37, C38, C42, C44, C46: 100nF; C_0603_HandSoldering; Part_Number C14663
C2, C3: 30pF; C_0603_HandSoldering; Part_Number C22397
C4, C6, C31, C33: 2.2uF; C_0805; Part_Number C49217
C18, C23, C27, C28: 560pF; C_0603_HandSoldering; Part_Number C84721
C22, C43: 10uF; C_0805; Part_Number C15850
C29, C30, C32, C34, C45: 1.5nF; C_0603_HandSoldering; Part_Number C1595
C36: 10uF; CP_Elec_3x5.3; Part_Number C249452
C39, C40: 22uF; CP_Elec_5x5.3
C41: 47uF; CP_Elec_5x5.3; Part_Number C134798
C47, C48: 1nF; C_0805; Part_Number C46653
C49, C50, C51, C52: 100pF; C_0805; Part_Number C1790
D2: LM4040DBZ-5; SOT-23; Part_Number C69316
D3, D4: 1N5819; D_SOD-123; Part_Number C169540
H1, H2: JLC_Tooling_Hole; JLC_SMT_Tooling_Hole
J1: SWD_Header; SWD_header
J2: Eurorack_10_pin_power; Eurorack_10_pin_header
J3, J4, J5, J6: Conn_01x08_Male; Pin_Header_Straight_1x08_Pitch2.54mm
J7: USB_B_Micro; USB_Micro-B_Amphenol
L1: L; L_0805_HandSoldering; Part_Number C1046
R1, R2, R10, R14, R18, R19: 30k; R_0603_HandSoldering; Part_Number C22984
R3, R15, R16, R17: 510R; R_0603_HandSoldering; Part_Number C23193
R4, R30: 91k; R_0603_HandSoldering; Part_Number C23265
R5, R24, R26: 100k; R_0603_HandSoldering; Part_Number C25803
R6, R8: 20k; R_0603_HandSoldering; Part_Number C4184
R7, R9, R27, R28, R31, R34: 47k; R_0603_HandSoldering; Part_Number C25819
R11: 56k; R_0603_HandSoldering; Part_Number C23206
R12, R13: 6k8; R_0603_HandSoldering; Part_Number C23212
R20, R21, R42, R43: 1k; R_0603_HandSoldering; Part_Number C21190
R22, R36, R37: 2k2; R_0603_HandSoldering; Part_Number C4190
R23, R25: 68k; R_0603_HandSoldering; Part_Number C23231
R29: 75k; R_0603_HandSoldering; Part_Number C23242
R32, R33: 330R; R_0603_HandSoldering; Part_Number C23138
R38, R39: 10k; R_0603_HandSoldering; Part_Number C25804
R40, R41: 33k; R_0603_HandSoldering; Part_Number C4216
TP1, TP2, TP3, TP4, TP5, TP6: TestPoint; Test_Point_Keystone_5005-5009_Compact
U1: STM32H743ZITx; LQFP-144_20x20mm_P0.5mm; Part_Number C114408
U2: IS42S16400J-xC; TSOP-II-54_22.2x10.16mm_P0.8mm; Part_Number C69411
U3: PCM5100APW; SSOP-20_4.4x6.5mm_Pitch0.65mm_Round_Pads; Part_Number C131154
U4: SSI2164; SOIC-16_3.9x9.9mm_Pitch1.27mm
U5, U6: MCP6004; SOIC-14_N; Part_Number C7378
U7: TL074; SOIC-14_N; Part_Number C6964
U8: LM1117-3.3; SOT-223; Part_Number C6186
Y1: 8MHz 20pF; Crystal_SMD_0603-2pin_6.0x3.5mm_HandSoldering

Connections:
+3.3VA: C13.1, C17.1, C21.2, C22.1, J3.1, J4.8, L1.1, TP3.1, U1.32 (VREF+), U1.33 (VDDA), U3.1 (CPVDD), U3.8 (AVDD), U5.4 (V+), U6.4 (V+), U6.12 (+)
+3V3: C1.2, C5.2, C7.2, C8.2, C9.2, C10.2, C11.2, C12.2, C14.2, C15.2, C16.2, C19.2, C20.2, C24.1, C25.2, C26.2, C37.2, C41.1, C42.2, C43.1, C44.2, C46.2, J1.1, L1.2, TP2.1, U1.6 (VBAT), U1.17 (VDD), U1.30 (VDD), U1.39 (VDD), U1.52 (VDD), U1.62 (VDD), U1.72 (VDD), U1.84 (VDD), U1.95 (VDD33_USB), U1.108 (VDD), U1.121 (VDD), U1.131 (VDD), U1.143 (PDR_ON), U1.144 (VDD), U2.1 (VDD), U2.3 (VDDQ), U2.9 (VDDQ), U2.14 (VDD), U2.27 (VDD), U2.43 (VDDQ), U2.49 (VDDQ), U3.11 (FLT), U3.17 (XSMT), U3.20 (DVDD), U8.2
+12V: D3.2 (A), J2.9, J2.10
-12V: D4.1 (K), J2.1, J2.2
/AUDIO_IN_L: C29.1, R12.1, U1.36 (PA2), U5.1
/AUDIO_IN_R: C30.1, R13.1, U1.37 (PA3), U5.7
/CLOCK: J4.6, U6.10 (+)
/CLOCK_SCALED: U1.43 (PA7), U6.8, U6.9 (-)
/DAC_BCLK: U1.117 (PD3), U3.13 (BCK)
/DAC_DATA: U1.29 (PC3_C), U3.14 (DIN)
/DAC_LRCLK: U1.140 (PB9), U3.15 (LRCK)
/DAC_OUT_AMP_L: R14.2, R42.1
/DAC_OUT_AMP_R: R10.2, R43.1
/DAC_OUT_L: R36.2, U3.6 (OUTL)
/DAC_OUT_R: R37.2, U3.7 (OUTR)
/DELAY_CHORUS: J6.1, U1.113 (PC12)
/DELAY_CV_L: J3.5, R24.2
/DELAY_CV_R: J3.6, R26.2
/DELAY_CV_SCALED_L: C32.1, R27.1, U1.34 (PA0), U5.8
/DELAY_CV_SCALED_R: C34.1, R28.1, U1.42 (PA6), U5.14
/DELAY_POT_L: J4.5, U1.47 (PB1)
/DELAY_POT_R: J5.6, U1.35 (PA1)
/DRY_OUT_L: C51.2, R18.2, U4.5 (I_OUT2), U4.12 (I_OUT3), U7.9 (-)
/DRY_OUT_R: C52.2, R19.2, U4.4 (I_OUT1), U4.13 (I_OUT4), U7.13 (-)
/EXT_AUDIO_IN_L: J3.3, R1.2, R7.2
/EXT_AUDIO_IN_R: J3.4, R2.2, R9.2
/EXT_AUDIO_OUT_L: J5.4, R20.1
/EXT_AUDIO_OUT_R: J5.5, R21.1
/FEEDBACK_CV: J4.4, R5.2
/FEEDBACK_CV_SCALED: C45.1, R11.1, U1.44 (PC4), U6.7
/FEEDBACK_POT: J4.3, U1.46 (PB0)
/FMC_A0: U1.10 (PF0), U2.23 (A0)
/FMC_A1: U1.11 (PF1), U2.24 (A1)
/FMC_A2: U1.12 (PF2), U2.25 (A2)
/FMC_A3: U1.13 (PF3), U2.26 (A3)
/FMC_A4: U1.14 (PF4), U2.29 (A4)
/FMC_A5: U1.15 (PF5), U2.30 (A5)
/FMC_A6: U1.50 (PF12), U2.31 (A6)
/FMC_A7: U1.53 (PF13), U2.32 (A7)
/FMC_A8: U1.54 (PF14), U2.33 (A8)
/FMC_A9: U1.55 (PF15), U2.34 (A9)
/FMC_A10: U1.56 (PG0), U2.22 (A10)
/FMC_A11: U1.57 (PG1), U2.35 (A11)
/FMC_BA0: U1.89 (PG4), U2.20 (BA0)
/FMC_BA1: U1.90 (PG5), U2.21 (BA1)
/FMC_D0: U1.85 (PD14), U2.2 (DQ0)
/FMC_D1: U1.86 (PD15), U2.4 (DQ1)
/FMC_D2: U1.114 (PD0), U2.5 (DQ2)
/FMC_D3: U1.115 (PD1), U2.7 (DQ3)
/FMC_D4: U1.58 (PE7), U2.8 (DQ4)
/FMC_D5: U1.59 (PE8), U2.10 (DQ5)
/FMC_D6: U1.60 (PE9), U2.11 (DQ6)
/FMC_D7: U1.63 (PE10), U2.13 (DQ7)
/FMC_D8: U1.64 (PE11), U2.42 (DQ8)
/FMC_D9: U1.65 (PE12), U2.44 (DQ9)
/FMC_D10: U1.66 (PE13), U2.45 (DQ10)
/FMC_D11: U1.67 (PE14), U2.47 (DQ11)
/FMC_D12: U1.68 (PE15), U2.48 (DQ12)
/FMC_D13: U1.77 (PD8), U2.50 (DQ13)
/FMC_D14: U1.78 (PD9), U2.51 (DQ14)
/FMC_D15: U1.79 (PD10), U2.53 (DQ15)
/FMC_SDCKE1: U1.135 (PB5), U2.37 (CKE)
/FMC_SDCLK: U1.93 (PG8), U2.38 (CLK)
/FMC_SD~E1: U1.136 (PB6), U2.19 (~CS)
/FMC_SD~WE: U1.26 (PC0), U2.16 (~WE)
/FMC_~BL0: U1.141 (PE0), U2.15 (LDQM)
/FMC_~BL1: U1.142 (PE1), U2.39 (UDQM)
/FMC_~CAS: U1.132 (PG15), U2.17 (~CAS)
/FMC_~RAS: U1.49 (PF11), U2.18 (~RAS)
/LED1: J6.3, R32.1
/LED2: J6.2, R33.1
/MIX_CV: J4.1, R30.2
/MIX_DRY_CTL: U1.40 (PA4), U4.11 (VC3), U4.14 (VC4)
/MIX_POT: J4.2, R31.2
/MIX_WET_CTL: U1.41 (PA5), U4.3 (VC1), U4.6 (VC2)
/MODE1: J5.7, U1.1 (PE2)
/MODE2: J5.8, U1.2 (PE3)
/RESET: J3.7, U1.25 (NRST)
/SWCLK: J1.4, U1.109 (PA14)
/SWIO: J1.3, U1.105 (PA13)
/TONE_POT: J3.8, U1.27 (PC1)
/USB_DM: J6.5, J7.2 (D-), U1.103 (PA11)
/USB_DP: J6.4, J7.3 (D+), U1.104 (PA12)
/USB_VBUS: J6.6, J7.1 (VBUS), U1.101 (PA9)
/WET_DRY_MIX: R34.1, U1.45 (PC5), U6.1
AREF_-5: C38.1, D2.2 (A), R4.2, R6.2, R8.2, R22.2, R23.2, R25.2, R29.2, TP4.1
GND: C1.1, C2.2, C3.2, C4.2, C5.1, C6.2, C7.1, C8.1, C9.1, C10.1, C11.1, C12.1, C13.2, C14.1, C15.1, C16.1, C17.2, C18.2, C19.1, C20.1, C21.1, C22.2, C23.2, C24.2, C25.1, C26.1, C27.2, C28.2, C33.2, C35.1, C36.2, C37.1, C38.2, C39.2, C40.1, C41.2, C42.1, C43.2, C44.1, C46.1, C47.2, C48.2, D2.1 (K), J1.2, J2.3, J2.4, J2.5, J2.6, J2.7, J2.8, J3.2, J4.7, J5.1, J5.2, J5.3, J6.7, J6.8, J7.5 (GND), TP1.1, U1.16 (VSS), U1.31 (VSSA), U1.38 (VSS), U1.51 (VSS), U1.61 (VSS), U1.83 (VSS), U1.94 (VSS), U1.107 (VSS), U1.120 (VSS), U1.130 (VSS), U1.138 (BOOT0), U2.6 (GNDQ), U2.12 (GNDQ), U2.28 (GND), U2.41 (GND), U2.46 (GNDQ), U2.52 (GNDQ), U2.54 (GND), U3.3 (CPGND), U3.9 (AGND), U3.10 (DEMP), U3.12 (SCK), U3.16 (FMT), U3.19 (DGND), U4.8 (GND), U5.3 (+), U5.5 (+), U5.10 (+), U5.11 (V-), U5.12 (+), U6.3 (+), U6.5 (+), U6.11 (V-), U7.3 (+), U7.5 (+), U7.10 (+), U7.12 (+), U8.1
unnamed: C2.1, U1.23 (PH0), Y1.2
unnamed: C3.1, U1.24 (PH1), Y1.1
unnamed: C4.1, U1.106 (VCAP2)
unnamed: C6.1, U1.71 (VCAP1)
unnamed: C18.1, R3.1
unnamed: C23.1, R15.1
unnamed: C27.1, R16.1
unnamed: C28.1, R17.1
unnamed: C29.2, R6.1, R7.1, R12.2, U5.2 (-)
unnamed: C30.2, R8.1, R9.1, R13.2, U5.6 (-)
unnamed: C31.1, U3.2 (CAPP)
unnamed: C31.2, U3.4 (CAPM)
unnamed: C32.2, R23.1, R24.1, R27.2, U5.9 (-)
unnamed: C33.1, U3.5 (VNEG)
unnamed: C34.2, R25.1, R26.1, R28.2, U5.13 (-)
unnamed: C35.2, U3.18 (LDOO)
unnamed: C45.2, R4.1, R5.1, R11.2, U6.6 (-)
unnamed: C47.1, R36.1, R38.2
unnamed: C48.1, R37.1, R39.2
unnamed: C49.1, R40.1, R42.2, U7.1
unnamed: C49.2, R38.1, R40.2, U7.2 (-)
unnamed: C50.1, R41.1, R43.2, U7.7
unnamed: C50.2, R39.1, R41.2, U7.6 (-)
unnamed: C51.1, R18.1, R20.2, U7.8
unnamed: C52.1, R19.1, R21.2, U7.14
unnamed: R1.1, R3.2, U4.10 (I_IN3)
unnamed: R10.1, R16.2, U4.2 (I_IN1)
unnamed: R14.1, R17.2, U4.7 (I_IN2)
unnamed: R2.1, R15.2, U4.15 (I_IN4)
unnamed: R29.1, R30.1, R31.1, R34.2, U6.2 (-)
unnamed: R32.2, U1.111 (PC10)
unnamed: R33.2, U1.112 (PC11)
unnamed: U6.13 (-), U6.14
VCC: C36.1, C39.1, D3.1 (K), TP5.1, U4.16 (V+), U7.11 (V-), U8.3
VEE: C40.2, D4.2 (A), R22.1, TP6.1, U4.9 (V-), U7.4 (V+)

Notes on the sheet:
Input Scaling
Power
Output Buffers
NOTE - Mode unconnected = Class AB 7.5k to VCC = Class A (Lower THD, higher noise)
POT Full scale: 3.3V CV Full scale: 6.4V
Wet Output Amplifiers
Full Scale: 7V
ADCs Used
Microcontroller
DRAM
Headers and Connectors
Output Amplifiers and Buffers
DAC and VCAs

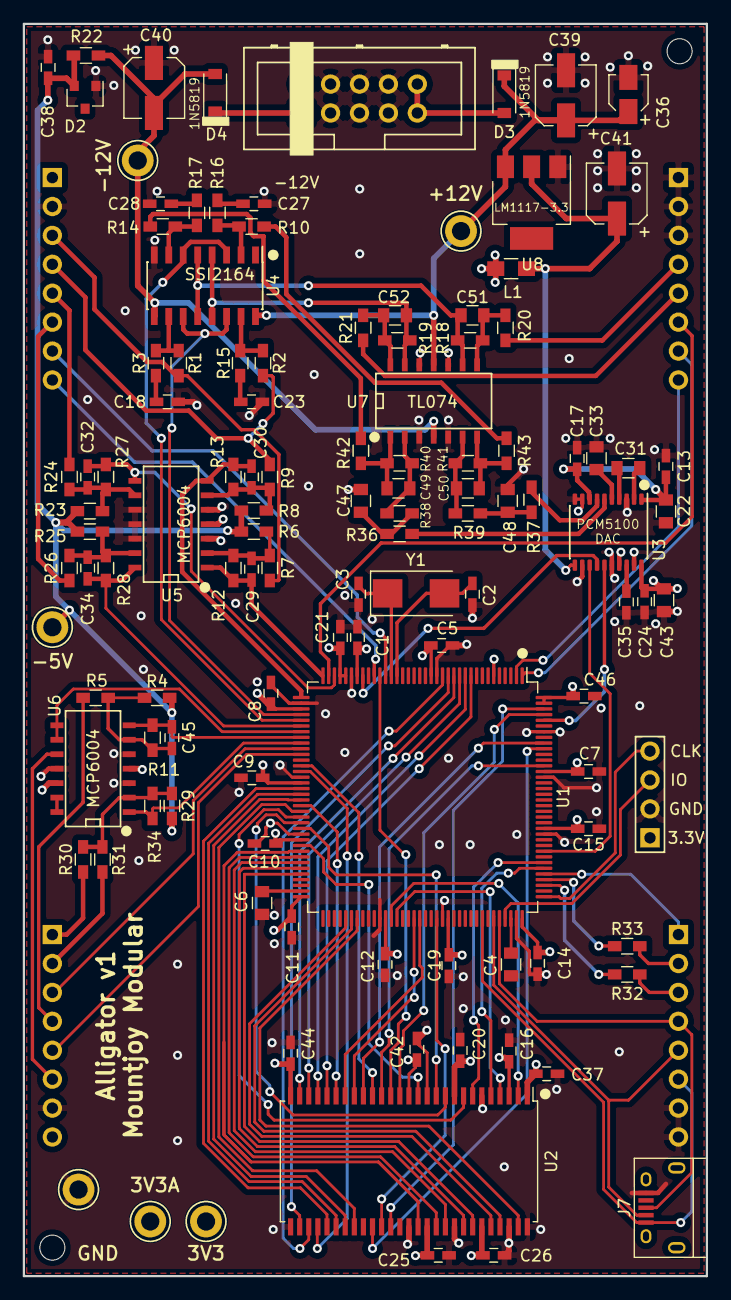
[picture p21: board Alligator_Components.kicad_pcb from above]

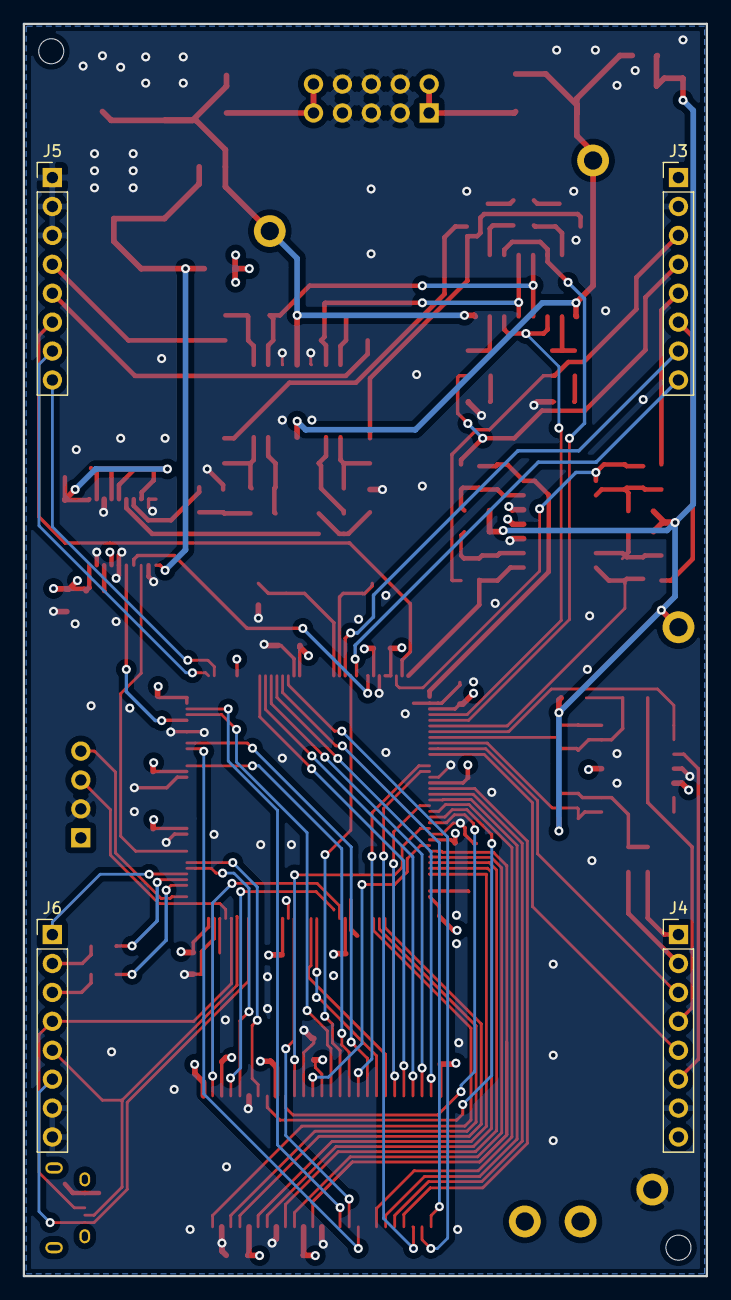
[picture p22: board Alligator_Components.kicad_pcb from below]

Board: 4 copper layers, 60.0 x 110.0 mm, 122 parts (4 on the bottom side), 122 nets.

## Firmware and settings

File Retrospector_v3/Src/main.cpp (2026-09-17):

#include "initialisation.h"
#include "USB.h"
#include "DigitalDelay.h"
#include "LEDHandler.h"
#include "configManager.h"
#include "Calib.h"

volatile uint32_t SysTickVal;
extern uint32_t SystemCoreClock;

// Store buffers that need to live in special memory areas
volatile uint16_t __attribute__((section (".dma_buffer"))) ADC_array[ADC1_BUFFER_LENGTH + ADC2_BUFFER_LENGTH];
__attribute__((section (".led_buffer"))) LEDHandler led;							// led handler in RAM_D3 as SPI6 uses BDMA which only works on this memory region
#ifdef NOEXTRAM
int32_t __attribute__((section (".ram_d1_data"))) samples[SAMPLE_BUFFER_LENGTH];	// Place delay sample buffers in external SDRAM
#else
int32_t __attribute__((section (".sdramSection"))) samples[SAMPLE_BUFFER_LENGTH];	// Place delay sample buffers in external SDRAM
#endif


extern "C" {
#include "interrupts.h"
}

Calib calib;
Filter filter;
DigitalDelay delay;

Config config{&calib.configSaver, &filter.configSaver, &delay.configSaver};			// Construct config handler with list of configSavers

uint32_t lastVal;

int main()
{

	InitHardware();
	led.Init();						// Initialise LED SPI packet
	config.RestoreConfig();			// Restore configuration settings (ADC offsets etc)
	filter.Init();					// Initialise filter coefficients, windows etc
	usb.Init(false);
	delay.Init();					// Clear sample buffers and preset delay timings
	InitI2S();						// Initialise I2S which will start main sample interrupts
	CopyToITCMRAM();				// Copy bootloader code to instruction RAM so it can update Flash

	while (1) {
		calib.AutoZeroOffset();		// Automatically adjust ADC zero offset during quiet sections
		delay.CheckSwitches();		// Check values of switches and detect link button press
		filter.Update();			// Check if filter coefficients need to be updated
		usb.cdc.ProcessCommand();	// Check for incoming USB serial commands
		config.SaveConfig();		// Save any scheduled changes

#if (USB_DEBUG)
		if ((GPIOB->IDR & GPIO_IDR_ID4) == 0 && USBDebug) {
			USBDebug = false;
			usb.OutputDebug();
		}
#endif

	}
}

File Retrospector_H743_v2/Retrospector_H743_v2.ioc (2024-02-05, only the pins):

Mcu.UserName=STM32H743ZITx
PA11.Signal=USB_OTG_FS_DM
PA12.Signal=USB_OTG_FS_DP
PA4.Signal=ADCx_INP18
PA5.Signal=COMP_DAC12_group
PA7.Signal=FMC_SDNWE
PA8.Signal=USB_OTG_FS_SOF
PA9.Signal=USB_OTG_FS_VBUS
PB0.GPIO_Label=LD1 [Green Led]
PB0.Signal=GPIO_Output
PB13.Signal=I2S2_CK
PB14.GPIO_Label=LD3 [Red Led]
PB14.Signal=GPIO_Output
PB15.Signal=I2S2_SDO
PB5.Signal=FMC_SDCKE1
PB6.Signal=FMC_SDNE1
PB7.Signal=I2C1_SDA
PB8.Signal=I2C1_SCL
PB9.Signal=I2S2_WS
PC0.Signal=ADCx_INP10
PC13.GPIO_Label=B1 [Blue PushButton]
PC13.Signal=GPIO_Input
PD0.Signal=FMC_D2_DA2
PD1.Signal=FMC_D3_DA3
PD10.Signal=FMC_D15_DA15
PD14.Signal=FMC_D0_DA0
PD15.Signal=FMC_D1_DA1
PD8.Signal=FMC_D13_DA13
PD9.Signal=FMC_D14_DA14
PE0.Signal=FMC_NBL0
PE1.Signal=FMC_NBL1
PE10.Signal=FMC_D7_DA7
PE11.Signal=FMC_D8_DA8
PE12.Signal=FMC_D9_DA9
PE13.Signal=FMC_D10_DA10
PE14.Signal=FMC_D11_DA11
PE15.Signal=FMC_D12_DA12
PE7.Signal=FMC_D4_DA4
PE8.Signal=FMC_D5_DA5
PE9.Signal=FMC_D6_DA6
PF0.Signal=FMC_A0
PF1.Signal=FMC_A1
PF11.Signal=FMC_SDNRAS
PF12.Signal=FMC_A6
PF13.Signal=FMC_A7
PF14.Signal=FMC_A8
PF15.Signal=FMC_A9
PF2.Signal=FMC_A2
PF3.Signal=FMC_A3
PF4.Signal=FMC_A4
PF5.Signal=FMC_A5
PF7.Signal=SPI5_SCK
PF9.Signal=SPI5_MOSI
PG0.Signal=FMC_A10
PG1.Signal=FMC_A11
PG15.Signal=FMC_SDNCAS
PG2.Signal=FMC_A12
PG4.Signal=FMC_A14_BA0
PG5.Signal=FMC_A15_BA1
PG7.GPIO_Label=USB_OTG_FS_OVCR
PG7.Signal=GPXTI7
PG8.Signal=FMC_SDCLK

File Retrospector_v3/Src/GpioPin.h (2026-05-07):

#pragma once


extern volatile uint32_t SysTickVal;

class GpioPin {
public:
	enum class Type {Input, InputPullup, InputPulldown, Output, AlternateFunction};
	enum class DriveStrength {Low, Medium, High, VeryHigh};
	enum class OutputType {PushPull, OpenDrain};

	GpioPin(GPIO_TypeDef* port, uint32_t pin, Type pinType, uint32_t alternateFunction = 0, DriveStrength driveStrength = DriveStrength::Low, OutputType outputType = OutputType::PushPull) :
		port(port), pin(pin), pinType(pinType)
	{
		Init(port, pin, pinType, alternateFunction, driveStrength);		// Init function is static so can be called without instantiating object
	}


	static void Init(GPIO_TypeDef* port, const uint32_t pin, const Type pinType, const uint32_t alternateFunction = 0, const DriveStrength driveStrength = DriveStrength::Low, OutputType outputType = OutputType::PushPull)
	{
		// maths to calculate RCC clock to enable
#if defined(STM32H723xx) || defined(STM32H747xx) || defined(STM32H743xx)
	const uint32_t portPos = ((uint32_t)port - GPIOA_BASE) >> 10;
	RCC->AHB4ENR |= (1 << portPos);
#elif defined(STM32H7B0xx)
	const uint32_t portPos = ((uint32_t)port - SRD_AHB4PERIPH_BASE) >> 10;
	RCC->AHB4ENR |= (1 << portPos);
#elif defined(STM32H563xx)
	const uint32_t portPos = ((uint32_t)port - AHB2PERIPH_BASE_NS) >> 10;
	RCC->AHB2ENR |= (1 << portPos);
#elif defined(STM32G473xx)
	const uint32_t portPos = ((uint32_t)port - AHB2PERIPH_BASE) >> 10;
	RCC->AHB2ENR |= (1 << portPos);
#elif defined(STM32F446xx) || defined(STM32F429xx)
	const uint32_t portPos = ((uint32_t)port - AHB1PERIPH_BASE) >> 10;
	RCC->AHB1ENR |= (1 << portPos);
#endif


		// 00: Input, 01: Output, 10: Alternate function, 11: Analog (reset state)
		if (pinType == Type::Input || pinType == Type::InputPullup || pinType == Type::InputPulldown) {
			port->MODER &= ~(0b11 << (pin * 2));
			if (pinType == Type::InputPullup) {
				port->PUPDR |= (0b1 << (pin * 2));
			} else if (pinType == Type::InputPulldown) {
				port->PUPDR |= (0b10 << (pin * 2));
			} else {
				port->PUPDR &= ~(0b11 << (pin * 2));
			}

		} else if (pinType == Type::Output) {
			port->MODER |=  (0b01 << (pin * 2));
			port->MODER &= ~(0b10 << (pin * 2));

		} if (pinType == Type::AlternateFunction) {
			port->MODER |=  (0b10 << (pin * 2));
			port->MODER &= ~(0b01 << (pin * 2));
			if (pin < 8) {
				port->AFR[0] |= alternateFunction << (pin * 4);
			} else {
				port->AFR[1] |= alternateFunction << ((pin - 8) * 4);
			}
		}

		port->OSPEEDR |= static_cast<uint32_t>(driveStrength) << (pin * 2);

		if (outputType == OutputType::OpenDrain) {
			port->OTYPER |= 1 << pin;
		}
	}


	static bool IsHigh(GPIO_TypeDef* port, const uint32_t pin) {
		return (port->IDR & (1 << pin));
	}

	bool IsHigh() {
		return (port->IDR & (1 << pin));
	}

	static bool IsLow(GPIO_TypeDef* port, const uint32_t pin) {
		return ((port->IDR & (1 << pin)) == 0);
	}

	bool IsLow() {
		return ((port->IDR & (1 << pin)) == 0);
	}

	static void SetHigh(GPIO_TypeDef* port, const uint32_t pin) {
		port->ODR |= (1 << pin);
	}

	void SetHigh() {
		port->ODR |= (1 << pin);
	}

	static void SetLow(GPIO_TypeDef* port, const uint32_t pin) {
		port->ODR &= ~(1 << pin);
	}

	void SetLow() {
		port->ODR &= ~(1 << pin);
	}

private:
	GPIO_TypeDef* port;
	uint32_t pin;
	Type pinType;
};


// Struct to manage buttons with debounce and GPIO management
struct Btn {
	GpioPin pin;
	uint32_t down = 0;			// set to zero if button has been pressed and is subsequently released
	uint32_t up = 0;			// Set to last release time
	bool longPressed = false;

	// Debounce button press mechanism
	bool Pressed() {
		// Has been pressed and now released
		if (pin.IsHigh() && down && SysTickVal > up + 100) {		// IsHigh = button not pressed
			down = 0;
			up = SysTickVal;
			if (longPressed) {
				longPressed = false;
				return false;
			}
			return true;
		}

		if (pin.IsLow() && down == 0 && SysTickVal > up + 100) {	// IsLow  = button pressed
			down = SysTickVal;
			up = 0;
		}
		return false;
	}

	bool LongPress() {
		if (pin.IsLow() && !longPressed && down && SysTickVal > down + 1000) {
			longPressed = true;
			return true;
		}
		return false;
	}

};

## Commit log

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2020-06-27 Fixed issues switching to high speed mode; USART working
    [initialisation.cpp, initialisation.h, main.cpp]
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2020-07-03 Removed HAL references and reorganised source code; updated UART to not use std::string; first draft of schematic
    [Alligator_Components.kicad_pcb, Alligator_Components.sch]
2020-07-07 Updates to schematic; Output ADC data over I2S via interrupt with L/R awareness
    [Alligator_Components PSRAM 100pin.sch, Alligator_Components.sch]
2020-07-10 Moved delay functionality to digitalDelay class; further working smoothing delay rate transitions
    [Alligator_Components.sch]
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2020-09-03 Attempt to identify zero crossing poinst when changing delay times (too slow)
    [main.cpp]
2020-09-07 Added initialisation and test code for DAC output; Schematic changes for first attempt at Wet/Dry mixer
    [Alligator_Components.sch]
2020-09-08 Implemented Wet/Dry mix control using MCU to process curves
    [Alligator_Components.sch]
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2020-09-10 Added remaining Opamp blocks to schematic and started control design
    [Alligator_Components.sch]
2020-09-11 First Draft of Component Schematic Done; Added enum for ADC input selction
    [Alligator_Components PSRAM 100pin.sch, Alligator_Components.sch]
2020-09-14 Initial pass at routing MCU and DRAM
    [Alligator_Components.kicad_pcb, Alligator_Components.sch]
2020-09-15 Further routing of PCB
    [Alligator_Components Draft 2.kicad_pcb, Alligator_Components.kicad_pcb, Alligator_Components.sch]
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2020-09-18 Error pass of schematic and PCB - power rails still need routing
    [Alligator_Components.kicad_pcb, Alligator_Components.sch]
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2020-09-30 Components first draft done; Started Controls PCB; Gerber and SMT assembly tests
    [Alligator_Components Draft 2.kicad_pcb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]
2020-09-30 Tooling holes added for SMT assembly; started routing control PCB
    [Alligator_Components.kicad_pcb, Alligator_Components.sch, Alligator_Controls.kicad_pcb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]
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2020-10-06 Renamed project files; work on panel PCB and 3d Models
    [Alligator_Panel.kicad_pcb, Retrospector_Components.kicad_pcb, Retrospector_Components.sch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]
2020-10-08 Added some test clock code using timer to capture clock interval in capture and compare input mode
    [Retrospector_Panel.kicad_pcb]
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2020-11-07 Reduced clock speed; started implementing SDRAM code; ADC updates
    [Retrospector_Components.kicad_pcb, Retrospector_Components.sch]
2020-11-10 Fixed USB (Enable VDD33USB supply level detector)
    [USB.cpp, initialisation.cpp]
2020-11-13 Fixed access to full 16MB of SDRAM and updated linker to map SDRAM address
    [main.cpp, sdram.cpp]
2020-11-15 Experiments with memory timing (currently working at 100MHz); tests with instruction and data cache; attempt to disable data cache for ADC (not working)
    [initialisation.cpp, main.cpp, sdram.cpp]
2020-11-16 MPU working correctly - data and instruction cache are enabled generally; data cache disabled for ADC DMA buffer
    [initialisation.cpp, initialisation.h, main.cpp]
2020-11-20 Started updating schematics and pcb layout for rev 2 changes; updated and tested clock pin to use production assignment
    [Retrospector_Components.kicad_pcb, Retrospector_Components.sch, Retrospector_Controls.sch]
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2020-11-22 Added Buck converter to PCB; other layout changes
    [Retrospector_Components.kicad_pcb, Retrospector_Components.sch]
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2020-11-23 Cleaned up project; basic delay functionality working on prototype 1
    [Retrospector_Components.kicad_pcb]
2020-11-23 Include inverting op amp output stage so output is not polarity reversed
    [Retrospector_Components.sch]
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2020-11-25 Initial schematics for power test boards with various chips
    [Retrospector_Power_Test_2.sch, Retrospector_Power_Test_LM2675.kicad_pcb, Retrospector_Power_Test_LM2675.sch]
2020-11-30 Power test PCBs finished and sent to production; basic implementation of clocked delay
    [Retrospector_Power_Test_LM2675-B_Cu.gbr, Retrospector_Power_Test_LM2675-B_Mask.gbr, Retrospector_Power_Test_LM2675-B_Paste.gbr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]
2020-12-02 Added project to support STM32F429 using same hardware; all components tested and working except I2S DAC
    [Retrospector_Power_Test_LM2675.sch]
2020-12-04 STM32F429 hardware support fully working;
    Proper implementation would require all ADC data to be scaled from 16 bit (H743) to 12 bit (F429)
    [Retrospector_F429.cfg]
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2020-12-15 Debugging DAC clock issues when using FMC to control SDRAM
    Workaround is to switch the clock for the I2S DAC to peripheral clock (also used by ADC at present)
    [Retrospector_Components.sch, Retrospector_Power_Test_LM2675.sch, Retrospector_Power_Test_TPS561201.kicad_pcb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]
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2020-12-17 Implemented basic FIR filter mechanism; Audio ADC and Control ADC separated
    [Retrospector_Components.sch]
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2020-12-21 Added option to dump right channel samples; fixed right channel output; fixed optimisation -O1 breaking USB output
    [CDCHandler.cpp, USB.h]
2020-12-22 Reduced ADC clock speed to 8.5 cycles to fix issue where ADC readings were 'bleeding' between controls
    [Retrospector_Components.sch]
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2020-12-27 Implemented preliminary feedback control; experiments smoothing delay times;
    Added volatile directives to prevent delay pots switching L/R
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2020-12-29 Mode siwtch allows choice between long and short delay times
    [CDCHandler.cpp, initialisation.cpp, initialisation.h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]
2020-12-30 Implemented reverse delay; mode switch selectes short, long and long reversed modes
    [initialisation.cpp, initialisation.h, main.cpp]
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2021-01-02 Fixes to LED code - still need to handle fractional tempo settings
    [initialisation.cpp, initialisation.h, main.cpp]
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2021-01-03 In reverse mode LEDs fade in to indicate delay length
    [Retrospector_H743 Debug.cfg]
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2021-01-05 Further work cleaning IIR code and trying to get HP IIR filter to behave correctly
    [CDCHandler.cpp, main.cpp]
2021-01-06 Further updates to IIR filtering; basically working though still glitching
    [CDCHandler.cpp, main.cpp]
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2021-01-15 Further updates of IIR LP to HP mode - still glitchy due to phase shifting differences between LP and HP modes
    [CDCHandler.cpp, main.cpp]
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2021-01-16 Fix to crossfade when changing filters
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2021-01-18 Added debug code to identify channel swapping issue
    [CDCHandler.cpp, initialisation.cpp, initialisation.h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]
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2021-01-19 Changed filter buffer size to 256 to avoid ring buffer navigation complications
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2021-01-24 Reworked chorus mode to use sample buffer in delay routine
    [CDCHandler.cpp, main.cpp]
2021-01-26 Tidied debug console; added class for fixed IIR filter; refactoring delay
    [CDCHandler.cpp, USB.cpp, main.cpp]
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2021-01-28 IIIR Filter used to smooth Filter ADC input
    [Retrospector_Components.kicad_pcb, Retrospector_Components.sch]
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2021-01-31 Added some basic test code for initialising I2C
    [Retrospector_Controls.sch]
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2021-02-05 Started work on v3 of PCB layout and schematic
    [Retrospector_Components-B_Cu.gbr, Retrospector_Components-B_Mask.gbr, Retrospector_Components-B_Paste.gbr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]
2021-02-09 Added some test code using SPI to control Toshiba LED controller
    [Retrospector_Components.kicad_pcb, Retrospector_Components.sch, Retrospector_Controls.sch]
2021-02-10 Basic tests of Toshiba LED Driver using SPI
    [Retrospector_Components.kicad_pcb]
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2021-02-13 SPI/DMA Led controller working correctly
    [LEDHandler.cpp, LEDHandler.h, initialisation.cpp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]
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2021-02-19 Added cycling test mode to RGB LED; Further updates to PCB layout
    [Retrospector_Components.kicad_pcb, Retrospector_Components.sch]
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2021-02-22 Further clean up to PCB; started work on using SPI for WS2812 LEDs
    [Retrospector_Components.kicad_pcb, Retrospector_Components.sch]
2021-02-24 Implemented mechanism for transmitting LED colours in WS2812 format using SPI and DMA
    [WS2812 Calc.xlsx]
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2021-03-06 Fix issue where starting chorus mode would result in loud thump
    [CDCHandler.cpp, main.cpp]
2021-03-17 Final updates to v2 PCBs for production; USB DFU Mode working
    [Retrospector_Components-B_Cu.gbr, Retrospector_Components-B_Mask.gbr, Retrospector_Components-B_Paste.gbr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]
2021-03-17 Unused code cleanup and refactor of CDC to serial class
    [Retrospector_Components-B_Cu.gbr, Retrospector_Components-B_Mask.gbr, Retrospector_Components-B_Paste.gbr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]
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2021-03-30 Bootloader mechanism can decode audio encoded data (basic implementation with limited error handling)
    [initialisation.cpp, initialisation.h, main.cpp]
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2021-04-03 Updated IO assignments; corrected position of 'Stereo wide' and 'Chorus' switches
    [Retrospector_Components.sch]
2021-04-03 Corrections to PCB for v3; implemented filter mode switch
    [Retrospector_Components.kicad_pcb, Retrospector_Controls.sch]
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2021-04-05 Updated SDRAM to work with 32MB RAM (implemented A12 line); attempts to get SPI DMA working for LED controller
    [Retrospector_Components.kicad_pcb, Retrospector_Components.sch]
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2021-04-09 Fixed left/right audio input to ADC; tempo lock implemented
    [DigitalDelay.cpp, initialisation.cpp, main.cpp]
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2021-04-11 Various fixes
    * Increase tempo Multiplier times for Long Delay
    * Implement RGB LED functionality for filter types
    * Link button improvements in long delay times
    * Fixes for noise when automating IIR filters
    [DigitalDelay.cpp, Filter.cpp, Filter.h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]
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2021-04-15 Debugging ADC issues
    [Retrospector_Components.sch]
2021-04-15 Fixed issues with calibration routine estimating too low; debug for ADC noise issues
    [DigitalDelay.cpp, initialisation.cpp, initialisation.h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]
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2021-05-01 Replaced chorus mechanism with modulated delay using interpolated samples
    [DigitalDelay.cpp, DigitalDelay.h, Filter.h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]
2021-05-02 Fixed issue where Modulated Delay mode would occasionally crash
    [DigitalDelay.cpp, initialisation.cpp]
2021-05-02 Added some handling to delay time hysteresis to avoid continually firing on long delay times
    [DigitalDelay.cpp, DigitalDelay.h]
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2021-05-06 Fixes to delay LED handling
    [DigitalDelay.cpp, main.cpp]
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2026-05-04 Fixed accidentally deleted design files
    [Retrospector_Controls.kicad_pcb, Retrospector_Panel.kicad_pcb]
2026-05-19 Fixed issues with stack in RAM_D1; Updated I2S to send two samples each interrupt
    Moved to DTCMRAM
    [DigitalDelay.cpp, DigitalDelay.h, initialisation.cpp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]
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
